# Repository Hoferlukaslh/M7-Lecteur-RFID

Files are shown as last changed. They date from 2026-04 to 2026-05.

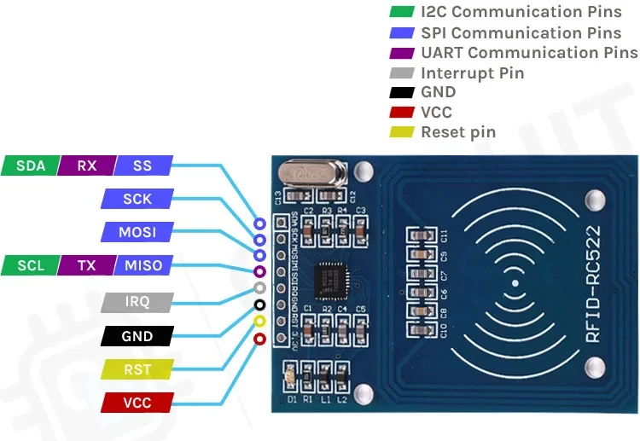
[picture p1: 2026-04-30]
Images/Hardware/RC522-RFID-Reader-Module-Pinout.webp

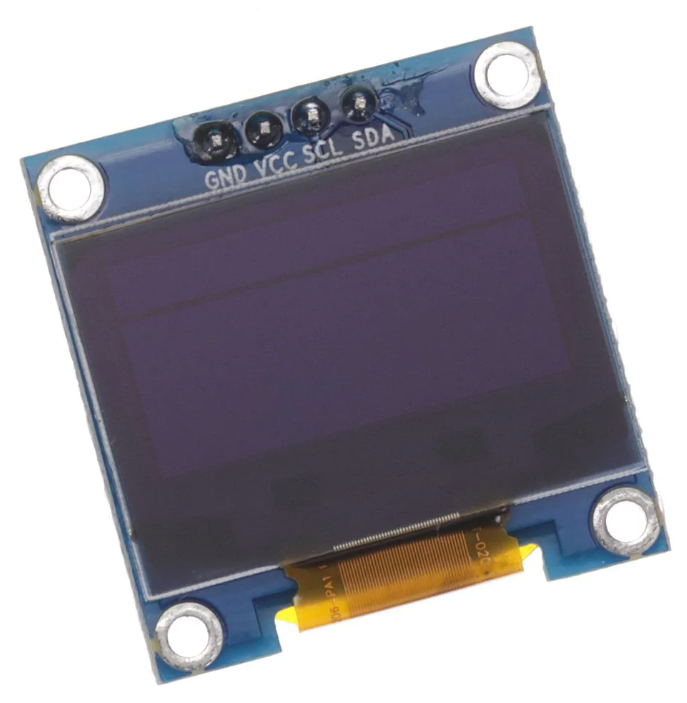
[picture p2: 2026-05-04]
Images/Hardware/OLED_SSD1305.png

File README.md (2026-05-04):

# M7-Lecteur-RFID
Ce dépôt contient l'ensemble des éléments du projet « Prototype de lecteur RFID » développé dans le cadre du module M7.    
L'objectif principal est de concevoir un système embarqué compact et bon marché, destiné à être dupliqué au sein des cellules de production des locaux de la NewTec.    
   
Ce système agit comme une interface physique et logique entre des tags RFID et un automate (PLC).   

[- Lien vers le dépot --](https://github.com/Hoferlukaslh/M7-Lecteur-RFID)

## Détails du projet 

### Architecture Globale et Communication
Le lecteur utilise une architecture de communication hybride pour s'adapter aux différents besoins de la ligne de production :

- Communication Automate (PLC) : Le système est universel et s'intègre avec tout type de contrôleur (Wago, Beckhoff, Raspberry Pi, etc.). Cette communication, servant à transmettre les ordres et les données lues, peut être activée ou désactivée selon les besoins de la cellule.

- Communication API (Wi-Fi) : De manière indépendante, le système interagit avec un serveur Node-RED via des requêtes API HTTP pour mettre à jour l'emplacement des palettes en temps réel dans une base de données. 

```mermaid
flowchart TD
    %% Définition des nœuds
    NR[Node-RED]
    DB[(BDD)]
    M7[Projet M7]
    PLC[Automate]

    %% Définition des liens et des étiquettes
    NR --> DB
    NR <-.->|"Requête API HTTP<br>(WiFi)<br>MàJ emplacement <br>palettes"| M7
    PLC -->|"Communication<br>pour ordres<br>(désactivable)"| M7
```

### Spécifications Matérielles
Le dispositif est conçu pour fonctionner de manière autonome dans un environnement industriel.

- Microcontrôleur : Choix libre.
- Module RFID : SBC-RFID-RC522.
- Connectivité : Wi-Fi avec antenne (choix libre).
- Alimentation : 24V DC (standard industriel).
- Cibles RFID : Petits disques de 15 mm x 3 mm disposant d'une capacité de stockage maximale de 106 octets.
- Intégration mécanique : Boîtier de protection imprimé en 3D. Il assure la sécurité du PCB et de l'antenne, tout en proposant un design universel pour une fixation rapide sur n'importe quelle structure machine sans gêner le flux des palettes.

### Spécifications Logicielles
Le firmware embarqué gère à la fois l'antenne RFID et la communication avec l'automate.  

#### Librairie RFID
Une bibliothèque logicielle est intégrée pour gérer la mémoire restreinte des tags avec les fonctions suivantes :

| Fonction | Description | 
| --- | --- |
| READ | Lecture des données présentes. |
| WRITE | Écriture avec écrasement du contenu existant. |
| APPEND | Ajout de nouvelles données à la suite (via gestion de pointeurs/marqueurs). |
| DELETE ALL | Effacement complet ou formatage du tag. |

#### Logique de Contrôle

| Fonction | Description | 
| --- | --- |
| Démarrage/Arrêt | Piloté sur commande du PLC. |
| Badge lu avec succès | Retour du contenu formaté au PLC et envoi de la mise à jour de position au serveur Node-RED. |
| Badge illisible/Erreur | Retour d'un code d'erreur spécifique au PLC. |
| Badge défectueux | Retour d'un code d'erreur critique (HS) au PLC. |
| Aucun badge | État d'attente, aucune action. |

### Ressources utilisées
#### Logiciels
| Logo | Application | Version | Utilité | Licence |
| :---: | :--- | :--- | :--- | --- |
|  | [**OnlyOffice**](https://www.onlyoffice.com) | 9.3.1 | Suite bureautique utilisée pour la rédaction et l’édition des documents du projet (DOCX, XLSX). | AGPL-3.0 |
|  | [**Draw.io**](https://github.com/jgraph/drawio) | 29.3.6 | Outil de conception de diagrammes. Utilisé pour la conception UML. | Apache 2.0 |
|  | [**VSCodium**](https://vscodium.com/) | v1.116.02821 | Editeur de texte avec extension (IDE) | MIT |
|  | [**Arduino IDE**](https://www.arduino.cc/en/software/) | 2.3.8 | IDE pour framework arduino (C++) | AGPL-3.0 |

### Modèle de Données et Optimisation
La contrainte matérielle majeure est la limite de 106 octets par tag. Une optimisation des données est indispensable.

#### Données des Palettes
- Identifiant de la palette.  
- Contenu de la palette : Jusqu'à 6 articles stockés sous le format `TTT-XXXXXX-VV-R` (Type de l'article, Code unique, Version, Révision).

#### Données des Badges Client :
- Identifiant de la palette.  
- Pseudonyme du client (10 caractères).  
- Données de production pour 4 cellules : Date, heure, et identifiant de la cellule ayant effectué l'opération.

## Livrables Attendus
L'arborescence de ce projet est divisée selon les livrables suivants :  

| Livrables | Description | 
| --- | --- |
| [Hardware](./Hardware/) | Dossier électronique contenant les schémas de principe, le routage PCB (fichiers Gerber) et la nomenclature (BOM). |
| [Mechanical](./Firmware/) | Fichiers 3D (STL/STEP) pour l'impression du boîtier de protection. |
| [Firmware](./Firmware/) | Code source documenté du microcontrôleur, incluant la pile de communication et la librairie RFID. |
| [Documents](./Documents/) | CdC et Journal, Documentation technique du projet (Table de communication décrivant le protocole PLC, les endpoints de l'API HTTP, et la cartographie d'optimisation mémoire) |
| [Images](./Images/) | Dossier contenant des images utilisés dans le projet. |

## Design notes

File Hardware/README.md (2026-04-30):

Dossier électronique contenant les schémas de principe, le routage PCB (fichiers Gerber) et la nomenclature (BOM).

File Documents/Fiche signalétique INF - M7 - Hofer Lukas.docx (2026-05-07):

2026 | AUTEUR : Prénom Nom EXPERTS : Prénom Nom, Ecole Supérieure Technique Prénom Nom, Nom de l’entreprise | « LOGO DE L’ENTREPRISE » Ou vide
Lecteur RFID

Objectifs

Développer un système embarqué compact et universel de lecture et d'écriture de tags RFID pour équiper les cellules de production de la NewTec.

Résultats

Conception et réalisation d'un circuit imprimé sur mesure intégrant un microcontrôleur ESP32-C6/S3, un module RFID RC522, et un étage d'alimentation abaisseur 24V vers 3.3V.

Développement d'un firmware sur FreeRTOS capable de gérer simultanément les bus de communication SPI (RFID), I2C (écran) et RS485 (automate).

Applications

Identification et traçabilité en temps réel des palettes circulant sur les différentes lignes de production automatisées.

Suivi décentralisé des étapes de production par horodatage et enregistrement des cellules traversées directement sur le tag physique.

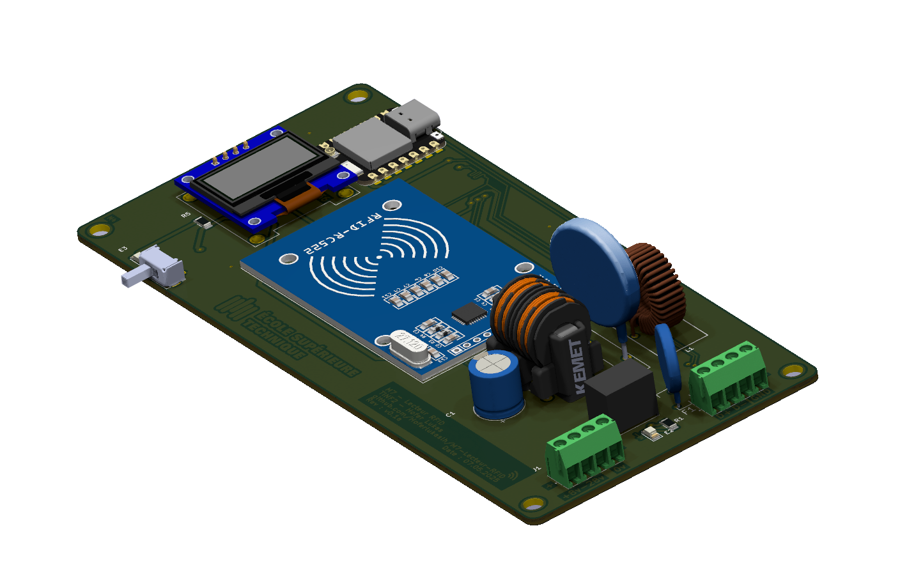
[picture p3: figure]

EST - Ecole Supérieure Technique Porrentruy

Informaticien·ne diplômé·e ES – Travail de module : M7-Internet des objets

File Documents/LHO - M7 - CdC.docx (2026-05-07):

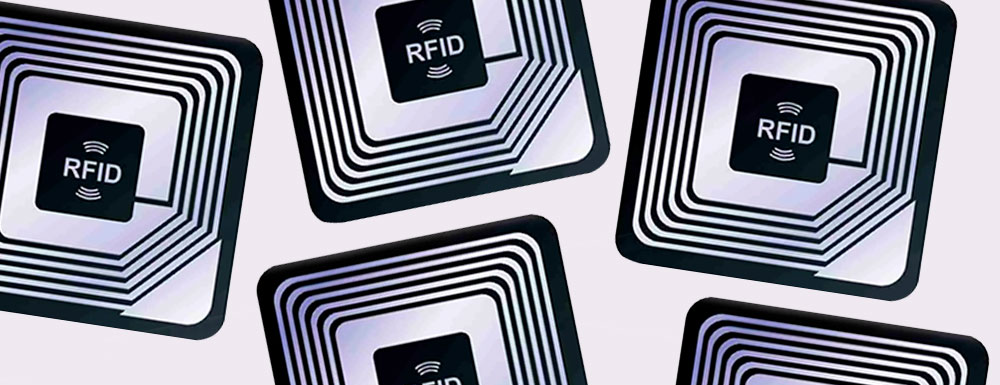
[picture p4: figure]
17 indicateurs de production à suivre - SupplyChainInfo

Lecteur RFID

M7 - Cahier des charges

Auteur :

Hofer Lukas
Technicien ES en informatique 2e année

Enseignants :

Claude Fahrni
Montfermé Arnaud
Montavon Dominique

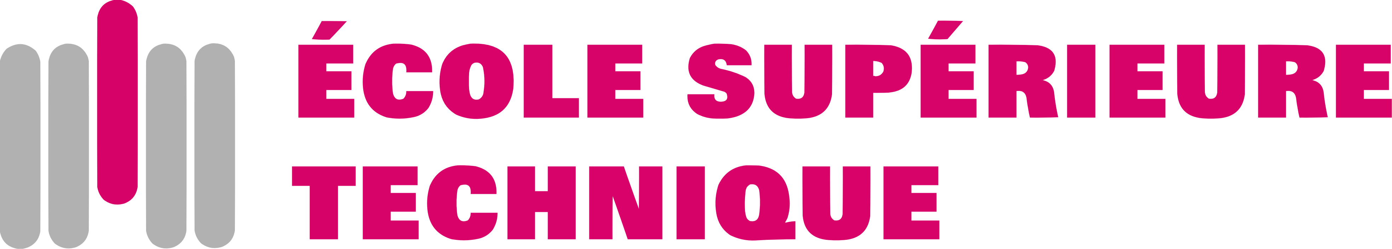
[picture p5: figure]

Avril 2026

École supérieure technique

# Introduction

Ce document définit les spécifications techniques et fonctionnelles pour le développement d'un système embarqué de lecture et d'écriture de tags RFID. Il s'inscrit dans le cadre global du projet « Prototype de lecteur RFID ».

Ce projet consiste à mettre au point un système embarqué compact et bon marché qui sera dupliqué et installé dans diverses cellules au sein des locaux de la NewTec. Le système servira d'interface physique et logique entre les tags RFID (en forme de petits disques) et le PLC.

## Architecture Globale et Communication

Le système possède désormais une architecture de communication hybride permettant de s'adapter aux différents besoins de la ligne de production.

- Communication Automate (PLC) : Le système doit être universel pour s'intégrer facilement à tout type de contrôleur (Wago, Beckhoff, etc.) ou Raspberry Pi. Cette communication PLC doit pouvoir être activable ou désactivable selon les besoins de la cellule (via un interrupteur par exemple).
- Protocole Automate : Le choix du protocole est à définir, avec une structure de trame stricte pour l'envoi des données lues et la réception des demandes d'écriture.
- Communication API (Suivi BDD) : Indépendamment de l'automate, le système M7 doit interagir avec un serveur Node-RED via des requêtes API HTTP. L’objectif est de Mettre à jour l'emplacement des palettes en temps réel dans une base de données (BDD) à chaque lecture d'un tag.

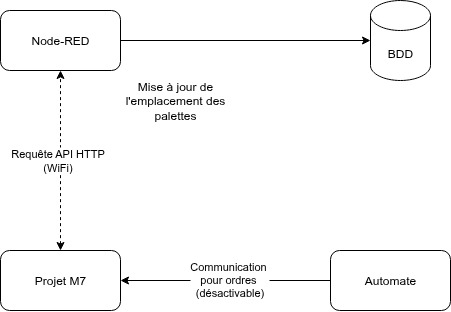
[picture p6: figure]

# Spécification matériel

Le système doit être conçu pour un environnement industriel et autonome dans son traitement local.

- Microcontrôleur : Choix libre.
- Communication API : Wi-Fi (antenne : choix libre)
- RFID : Module SBC-RFID-RC522
- Alimentation : Le système sera alimenté en 24V DC (standard industriel).
- Tags RFID cibles :
  - Dimensions physiques : 15 mm x 3 mm.
  - Capacité de stockage mémoire : 106 octets (bytes) maximum.
- Conception Électronique (PCB) :
  - Création du schéma de principe.
  - Routage de la carte électronique (PCB).
  - Fabrication et assemblage.
- Intégration Mécanique :
  - Conception et modélisation 3D d'un boîtier de protection.
  - Fabrication par impression 3D.

## Conception du boîtier et intégration

Le système embarqué devra être intégré dans un boîtier de protection réalisé par impression 3D.

La conception mécanique de ce boîtier devra répondre à deux exigences principales :

- Protection : Assurer la sécurité de la carte électronique et de l'antenne RFID dans un environnement industriel standard.
- Installation universelle : Prévoir un design et des points de fixation simples permettant de monter le boîtier facilement et rapidement sur n'importe quelle structure de machine ou au sein d'une zone automate.

L'encombrement global devra être pensé pour ne pas gêner le flux des palettes ni l'accès aux autres équipements.

# Spécifications Logicielles

Le microcontrôleur devra embarquer un programme gérant à la fois l'antenne RFID et le dialogue avec l'automate.

## Librairie RFID

Développement ou intégration d'une bibliothèque logicielle permettant la gestion de la mémoire restreinte des tags avec les fonctions suivantes :

- READ : Lecture des données présentes sur le tag.
- WRITE : Écriture de données en écrasant le contenu existant.
- APPEND : Ajout de nouvelles données à la suite des données existantes (nécessite une gestion des pointeurs ou marqueurs de fin de fichier).
- DELETE ALL : Effacement complet ou formatage de la mémoire du tag.

## Logique de Contrôle

Le programme principal doit réagir aux requêtes selon la logique suivante :

- Démarrage/Arrêt Gérer le lancement et l'arrêt de la procédure de lecture sur commande du PLC.
- Badge lu avec succès Retourner l'intégralité du contenu formaté au PLC et envoyer la mise à jour de position au serveur HTTP Node-RED.
- Badge illisible ou Erreur Retourner un code d'erreur spécifique au PLC.
- Badge défectueux Retourner un code d'erreur critique (HS) au PLC.
- Aucun badge Ne déclencher aucune action (état d'attente).

# Modèle de Données

La contrainte majeure du projet est la limite physique de 106 octets par tag RFID.

## Données des palette

- Identifiant de la palette
- Contenu de la palette : Jusqu'à 6 articles au format TTT-XXXXXX-VV-R

T | T | T | - | X | X | X | X | X | X | - | V | V | - | R
Type de l’article | | | | Code unique de l’article | | | | | | | Version | | | Révision

Exemple :

Paramètre | Contenu
Identifiant de la palette | P2
Emplacement 1 | 001 - 000000 - 00 - 0
Emplacement 2 | 010 - 000000 - 00 - 1
Emplacement 3 | 100 - 000000 - 00 - 1
Emplacement 4 | 900 - 000000 - 00 - 2
Emplacement 5 | 999 - 000000 - 00 - 8
Emplacement 6 | 888 - 000000 - 00 - 9

Une optimisation est nécessaire afin de réduire l’espace mémoire utilisé.

## Données des badges client

- Identifiant de la palette
- Pseudonyme du client : 10 caractères.
- Données de production
  - Date et heure
  - Identifiant des cellules ayant effectuée les opérations (fixé à 4 actuellement)
  - Identifiant de la palette utilisé pour la prodution

Exemple :

Paramètre | Contenu
Identifiant de la palette | P2
Pseudonyme | HoferLukas
Identifiant cellule 1 | C1
Date et heure cellule 1 | 12:05:02 - 22/04/26
Identifiant cellule 2 | C2
Date et heure cellule 2 | 12:06:08 - 22/04/26
Identifiant cellule 3 | C3
Date et heure cellule 3 | 12:08:55 - 22/04/26
Identifiant cellule 4 | C4
Date et heure cellule 4 | 12:10:32 - 22/04/26

Une optimisation est nécessaire afin de réduire l’espace mémoire utilisé.

# Livrables Attendus

- Dossier électronique Fichiers schématiques, fichiers Gerber pour la fabrication du PCB, et BOM (Nomenclature).
- Dossier mécanique Fichiers STL/STEP pour l'impression 3D du boîtier.
- Code source Firmware du microcontrôleur documenté, incluant la librairie RFID et la pile de communication.
- Table de communication Document décrivant le protocole choisi, la structure des trames d'échange PLC, les endpoints de l'API HTTP, et la cartographie d'optimisation mémoire des 106 octets.
- Prototype fonctionnel Carte électronique assemblée dans son boîtier avec firmware opérationnel.

LHO - M7 - CdC - v2.docx Page 2 sur 6 LHO/30.04.2026

Cahier des charges M7 TINF2

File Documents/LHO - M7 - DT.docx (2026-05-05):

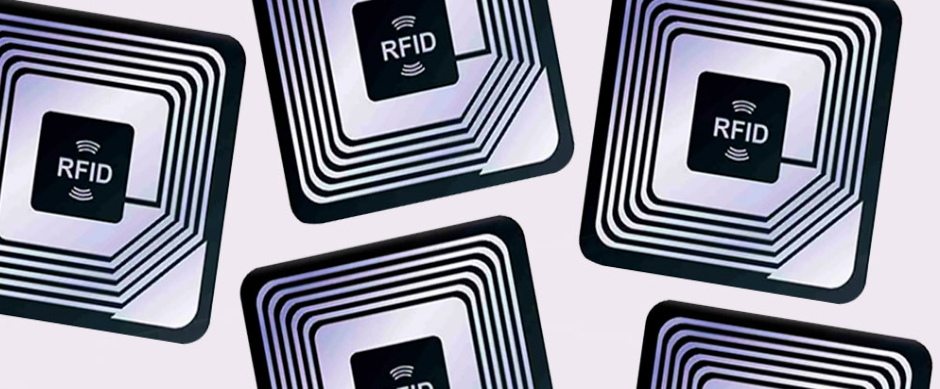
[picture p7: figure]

Lecteur RFID

M7 - Documentation technique

Auteur :

Hofer Lukas
Technicien ES en informatique 2e année

Enseignants :

Claude Fahrni
Arnaud Montfermé
Montavon Dominique


Avril - Juin 2026

École supérieure technique

# 1. Introduction

Ce module d’apprentissage a pour objectif de couvrir l’ensemble du cycle de développement d'un système embarqué de lecture et d'écriture de tags RFID , depuis l’analyse des besoins jusqu’aux phases de fabrication, de test et de validation du prototype.

Il met l’accent sur les bonnes pratiques de conception matérielle et logicielle, l'intégration dans un environnement industriel, et l’utilisation d’outils de développement professionnels.

Les compétences visées sont les suivantes :

- Conception électronique : Création de schémas de principe, routage de la carte électronique (PCB) et assemblage des composants.
- Conception mécanique : Modélisation 3D et impression d'un boîtier de protection adapté à une installation universelle sur ligne de production.
- Développement logiciel embarqué : Programmation d'un microcontrôleur et intégration d'une librairie RFID pour la lecture, l'écriture et la gestion d'une mémoire restreinte.
- Architecture de communication : Mise en œuvre d'une communication hybride comprenant un protocole strict avec un automate (PLC) et des requêtes API HTTP vers Node-RED.

## 1.1 Personnes impliquées

Élève impliqué :

- Hofer Lukas : technicien ES en informatique 2e année

Enseignants impliqués :

- Claude Fahrni : responsable du module et suivit technique du projet
- Montfermé Arnaud : suivi technique du projet
- Montavon Dominique : suivi technique du projet

## 1.2 Directives générales

### 1.2.1 Délais

Réedition des documents | 12 Juin 2026
Présentation | 17 Juin 2026
Remise du travail complet | 18 Juin 2026

### 1.2.2 Livrables

- Cahier des charges
- Documentation technique (ce présent document)
- Présentation
- Planification (avec suivit)
- Journal de travail
- Prototype fonctionnel (PCB)

# 2. Spécifications du système

Le projet consiste à développer un appareil embarqué permettant à l’installation de :

Assurer l'interface physique et logique entre des tags RFID et un automate industriel (PLC).

Identifier et tracer les palettes circulant sur la ligne de production en temps réel.Gérer le stockage de données de production et d'articles dans une mémoire restreinte de 106 octets.

Communiquer de manière hybride avec un automate (commandes locales) et un serveur Node-RED (mise à jour de base de données via API).

## 2.1 Cible

Ce projet part de trois constats principaux :

- Besoin de modularité : Nécessité d'un système compact et bon marché pouvant être dupliqué et installé facilement sur n'importe quelle structure.
- Interopérabilité : Besoin d'un lecteur universel capable de communiquer avec différents types de contrôleurs (Wago, Beckhoff, Raspberry Pi).
- Digitalisation : Volonté d'automatiser la mise à jour des emplacements de palettes dans une base de données centrale indépendamment de l'automate.

## 2.2 Exigences fonctionnelles

Les fonctionnalités suivantes devront être implémentées

ID | Catégorie | Description de l'exigence | Priorité
REQ-F-001 | RFID | Le système doit permettre la lecture (READ), l'écriture (WRITE) et l'ajout (APPEND) de données sur les tags. | Haute
REQ-F-002 | Comm. PLC | Le système doit échanger des trames de données strictes avec l'automate pour l'envoi des lectures et la réception d'ordres. | Haute
REQ-F-003 | Sync. API | Le système doit envoyer une requête HTTP à un serveur Node-RED à chaque lecture réussie pour mettre à jour la BDD. | Haute
REQ-F-004 | Gestion Mémoire | Le système doit optimiser l'encodage des données pour respecter la limite physique de 106 octets par tag. | Haute
REQ-F-005 | Diagnostic | Le système doit retourner des codes d'erreurs spécifiques au PLC en cas de tag illisible, défectueux ou absent. | Moyenne
REQ-F-006 | Contrôle Local | La communication avec l'automate doit pouvoir être activée ou désactivée manuellement via un interrupteur. | Basse
REQ-F-007 | Intégration | Implémentation sur PCB et intégration dans un boitier pouvant facilement être integré dans un environnement industriel. | Basse

# 3. Conception Matérielle

La conception matérielle fait partie du premier sprint. Elle sert à concevoir un prototype le plus rapidement possible.

## 3.1 Vue d'ensemble de l'architecture

L'architecture matérielle proposée a été pensée pour répondre aux contraintes de compacité, de coût et de double communication (Automate et Base de données).

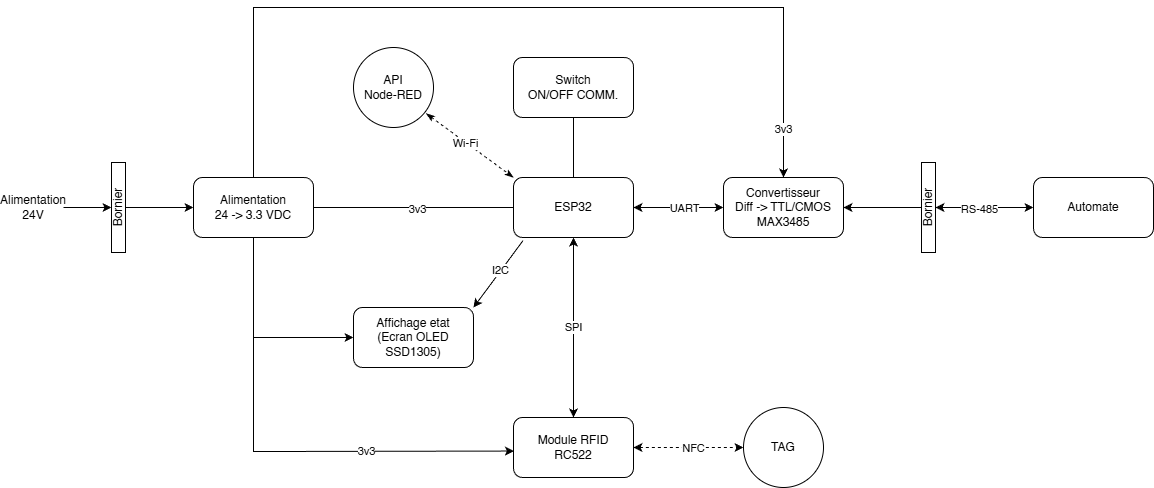
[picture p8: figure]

Le système s'articule autour d'un microcontrôleur central faisant le pont entre le monde industriel (borniers 24V et RS-485) et les périphériques de lecture matérielle et de communication sans fil (RFID et Wi-Fi).

## 3.1 Choix des composants

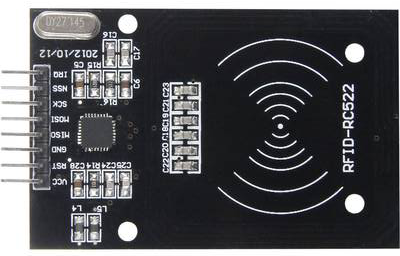
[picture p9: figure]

### 3.1.1 Module de lecture RFID : RC522

Le choix de ce module n'a pas été libre, il a été imposé par le cahier des charges. Il s'agit d'un lecteur RFID fonctionnant avec une tension logique de 3.3V et qui communique avec le microcontrôleur via le bus SPI.

### 3.1.2 Interface Automate (PLC) : RS-485 et MAX3485

Pour garantir la compatibilité universelle du prototype avec différents contrôleurs industriels (Wago, Beckhoff, etc.), l'interface de communication physique devait être robuste.

- Bus de terrain RS-485 : Le standard industriel RS-485 a été choisi pour le câblage vers l'automate. Ses signaux différentiels offrent une forte résistance aux interférences électromagnétiques fréquentes dans les milieux de production.
- Convertisseur : L'ESP32 utilisant des signaux TTL/CMOS sur son port UART, une puce de conversion MAX3485 est intégrée. Elle sert de pont pour traduire les signaux logiques de l'ESP32 en signaux différentiels exploitables par l'automate via le bornier de raccordement. L'avantage du MAX3485 est qu'il est alimenté directement en 3.3V, simplifiant ainsi le circuit.

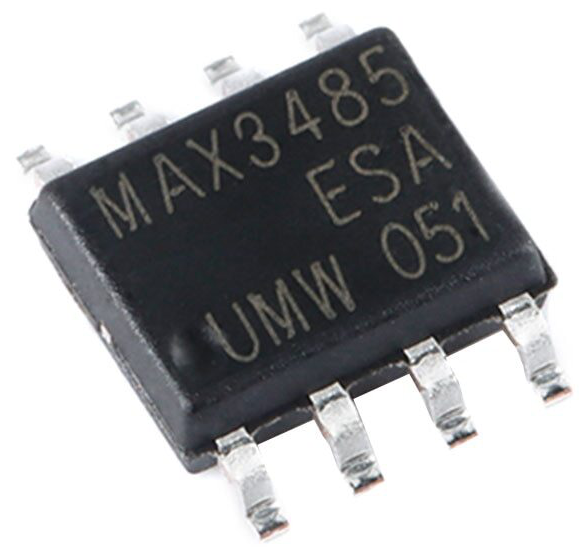
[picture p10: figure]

### 3.1.3 Affichage / Autodiagnostique : Ecran OLED


Cet affichage permet de remonter le diagnostic local (état d'attente, badge lu avec succès, badge illisible, ou badge défectueux). Le choix s'est porté sur l’afficheur OLED basé sur le contrôleur SSD1305, car il est déjà à disposition. (exigences REQ-F-005)

### 3.1.4 Interfaces de contrôle local et de diagnostic

Afin de répondre aux exigences d'intégration logicielle et matérielle du cahier des charges (exigences REQ-F-006), des interfaces physiques dédiées aux opérateurs ont été ajoutées :

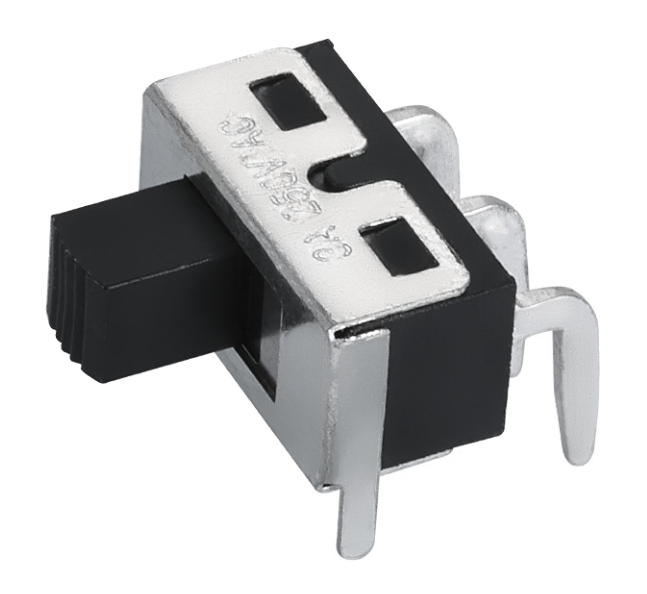
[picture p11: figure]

- Switch ON/OFF COMM : Un interrupteur matériel relié à une broche d'entrée de l'ESP32. Il permet à l'opérateur d'activer ou de désactiver la communication série avec l'automate. J’ai choisi de prendre un switch latéral pour l’accessibilité à l’éxtérieur du boitier.

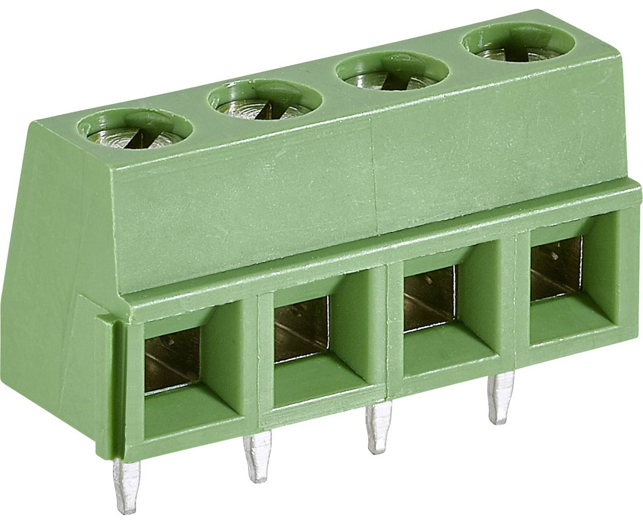
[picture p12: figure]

### 3.1.5 Branchement / Liaison

Afin de garantir une intégration rapide et une utilisation aisée sur les lignes de production, les liaisons physiques entre la carte électronique et l'extérieur du boîtier sont réalisées au moyen de borniers (terminal blocks).

Ce choix de conception est particulièrement adapté aux contraintes du milieu industriel pour les raisons suivantes :

- Facilité et rapidité d'installation : Le raccordement de l'appareil s'effectue à l'aide d'un simple tournevis, sans nécessiter de fiches spécifiques, d'outils de sertissage complexes ou de soudures sur site.
- Maintenance simplifiée (Plug & Play) : En cas de défaillance matérielle, l'opérateur peut dévisser ou débrocher les borniers pour retirer le lecteur défectueux et brancher un nouveau prototype en quelques secondes.

### 3.1.6 Microcontroleur : ESP32-S3/C6

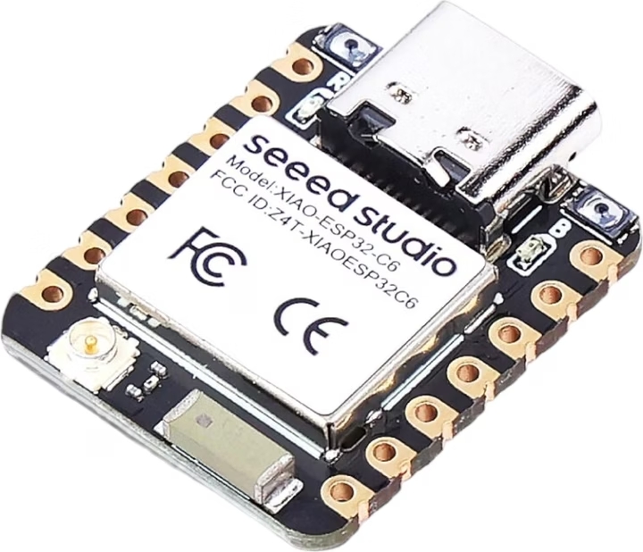
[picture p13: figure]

Pour le rôle de traitement central, le choix s'est porté sur le microcontrôleur Seeed Studio XIAO ESP32S3/C6. Ce composant a été sélectionné pour plusieurs raisons stratégiques permettant de répondre aux contraintes d'encombrement et de communication du cahier des charges :

- Connecteur pour antenne externe (U.FL / IPEX) : Le XIAO ESP32S3/C6 est équipé d'un connecteur physique permettant de déporter l'antenne Wi-Fi à l'extérieur du boîtier ou de la machine. C'est un avantage décisif pour contourner les interférences des structures métalliques industrielles et garantir des requêtes API HTTP stables vers le serveur Node-RED.
- Intégration optimisée sur PCB : Grâce à ses pastilles crénelées (castellated holes), ce module peut être soudé directement à plat en tant que composant monté en surface (CMS) sur la carte électronique mère, garantissant une forte résistance mécanique aux vibrations de la ligne de production.
- Tension logique (3.3V) : Le microcontrôleur fonctionne avec une tension de 3.3V, ce qui lui permet de communiquer directement avec le module RC522 et la puce MAX3485 sans nécessiter de convertisseurs de niveaux logiques (Level Shifters) supplémentaires, simplifiant ainsi le routage global.
- Maturité : ESP32 est une plateforme extrêmement mature et standardisée. Elle dispose d'une vaste communauté, d'une excellente documentation et de nombreuses bibliothèques éprouvées. Cela permet de réduire les risques lors du développement logiciel et d'accélérer la réalisation du prototype.
- Gestion multi-bus (Optimisation des I/O) : Bien que le format compact du XIAO n'offre que 11 broches GPIO latérales, l'architecture matérielle a été rigoureusement calculée pour les exploiter à 100 %. Grâce à la matrice GPIO programmable de l'ESP32 (qui permet de réassigner librement les bus de communication pour faciliter le routage du PCB), ces 11 broches suffisent exactement à couvrir l'intégralité des périphériques :
  - 5 broches pour le module RFID-RC522
  - 3 broches pour l'interface automate via le MAX3485
  - 2 broches dédiées au diagnostic visuel via l’écran (I2C)
  - 1 broche pour l'interrupteur matériel de la communication locale
- Disponibilité et expérience : Ayant auparavant travaillé avec ce même modèle, cela élimine les temps d'apprentissage (pas de surprises techniques) et sécurise la phase de développement logiciel. De plus, la disponibilité immédiate d'un modèle d'évaluation permet de démarrer la phase de prototypage et les premiers tests sans subir de délais d'approvisionnement (ESP32-C6).

### 3.1.7 Gestion de l'alimentation : (24v ->3v3)

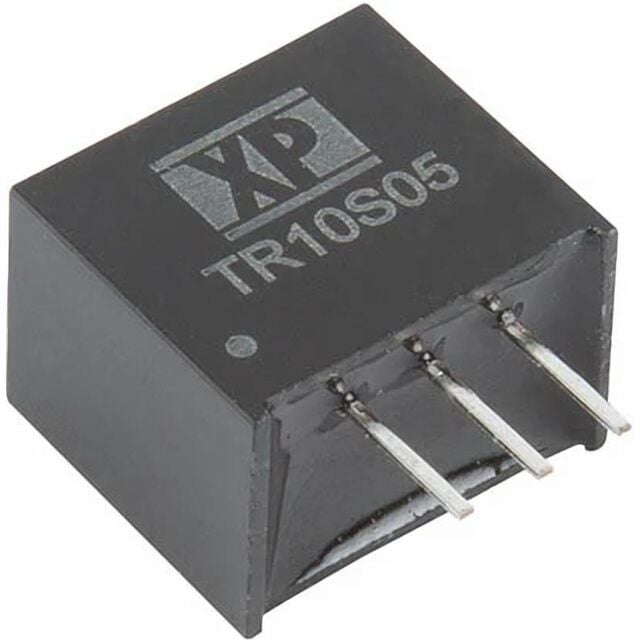
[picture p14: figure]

Le système devant s'intégrer directement dans les cellules industrielles, l'alimentation primaire fournie en entrée est le standard 24V DC. Pour abaisser et réguler cette tension, le choix s'est porté sur le convertisseur DC-DC TSR 1-2433E.

Il s'agit d'un régulateur à découpage, capable d'accepter une large plage de tension en entrée (de 6V à 36V) pour fournir une tension de sortie stable de 3.3V.

Il peut délivrer un courant allant jusqu'à 1A (1000 mA), avec une excellente efficacité énergétique pouvant atteindre 88%.

Cette haute efficacité minimise considérablement la dissipation thermique, ce qui est idéal pour un boîtier fermé imprimé en 3D, tout en garantissant un encombrement minimal sur le PCB.

### 3.1.8 Bilan de puissance (Calculs)

Afin de valider le choix du régulateur TSR 1-2433E, un bilan de puissance a été réalisé en prenant en compte la consommation maximale théorique de chaque composant actif sur la ligne 3.3V :

- Microcontrôleur ESP32 (S3 ou C6) : Lors d'un pic d'émission Wi-Fi (transmission 802.11b à pleine puissance), la consommation maximale est d'environ 354 mA.
- Module de lecture RFID (RC522) : En phase de fonctionnement et de lecture active (émission du champ à 13.56 MHz), la consommation maximale est de 26 mA.
- Transceiver RS-485 (MAX3485) : Le courant d'alimentation de la puce est d'environ 2.2 mA au maximum. En ajoutant le courant de pilotage sur le bus avec une charge standard, on peut estimer un maximum d'environ 60 mA.
- Afficheur OLED et signalisation : L'écran OLED tous pixels allumés et les deux LEDs de statut consomment ensemble un maximum estimé à 50 mA.

Calcul de la charge totale maximale :

354 mA+26 mA+60 mA+50 mA=490 mA

Le courant maximal appelé par le circuit en pic d'activité est d'environ 490 mA. Le régulateur TSR 1-2433E pouvant fournir jusqu'à 1000 mA, le système fonctionnera à moins de 50 % de la capacité maximale du convertisseur.

Cette large marge de sécurité garantit que l'alimentation ne subira aucune surchauffe ni chute de tension, assurant ainsi la stabilité de l'ensemble du système.

## 3.2 Schéma de principe et implémentation électrique

Cette section détaille la traduction des choix matériels en un schéma électronique concret. Le circuit a été divisé en plusieurs blocs fonctionnels pour faciliter le routage et la compréhension du système.

### 3.2.1 Bloc Alimentation (Protections, Filtrage et Régulation)

Le circuit d'alimentation est le bloc le plus critique, chargé de sécuriser et d'abaisser la tension industrielle de 24V vers le 3.3V logique. Il est divisé en trois étages successifs :

- Étage de protection (Entrée +8V à 28V) : L'alimentation arrive par le bornier J1. Elle traverse immédiatement une diode Schottky D1 (BX36_R1) pour bloquer toute inversion de polarité, suivie d'un fusible réarmable F1 (PTC 1A) contre les surintensités. Une diode TVS D2 (SMAJ28A, Vz = 28V) écrête les surtensions transitoires.
- Étage de filtrage CEM (EN 55032 Classe B) : Pour respecter les normes d'émissions, la tension (désormais entre +7V et 27.6V) passe par un filtre rigoureux. Une varistance RV1 (20D470K) protège l'entrée du filtre. Le lissage basse fréquence est assuré par l'inductance L1 (300 µH) et les condensateurs C1 (470 µF) et C2 (4.7 µF). Le filtrage haute fréquence et asymétrique est géré par l'inductance de mode commun L2 (5 mH) et le condensateur C3 (10 µF).
- Étage de régulation : Le convertisseur DC-DC PS1 (TSR 1-2433E) abaisse la tension à +3V3. La sortie est stabilisée par un condensateur C4 (22 µF) et alimente une LED de fonctionnement E2 via une résistance R1 (68 R)

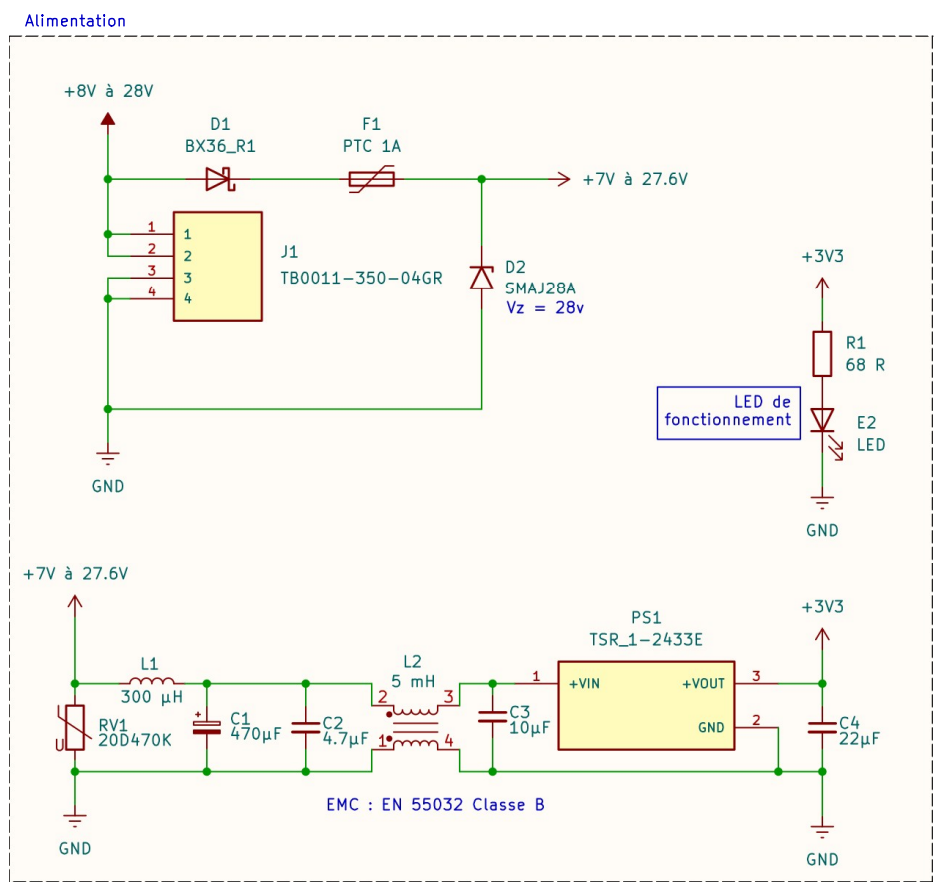
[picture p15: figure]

### 3.2.2 Microcontrôleur

Le composant U1 (XIAO-ESP32-C6, compatible S3) centralise toutes les liaisons.

Alimenté en +3V3, il orchestre les différents bus de communication (SPI pour le RFID, I2C pour l'écran, UART pour le RS-485) ainsi que les entrées/sorties numériques directes (comme le switch de commande).

### 3.2.3 Communication Automate (Interface RS-485)

L'interface de communication vers le PLC est gérée par le transceiver U3 (MAX3485CSA+T), alimenté en +3V3.

- Logique de contrôle : Les broches DI (Data In) et RO (Receiver Out) sont reliées au port UART de l'ESP32 (broches TX et RX). Les broches d'activation DE (Driver Enable) et RE (Receiver Enable) sont court-circuitées et pilotées par une seule broche GPIO de l'ESP32 : un état HAUT (HIGH) active l'envoi de données, tandis qu'un état BAS (LOW) place la puce en mode écoute.
- Liaison physique : Les signaux différentiels de sortie D+ et D- sont dirigés vers le bornier J2. Une résistance de terminaison R2 (120 R) est placée en parallèle entre ces deux lignes pour empêcher la réflexion des signaux en bout de ligne.

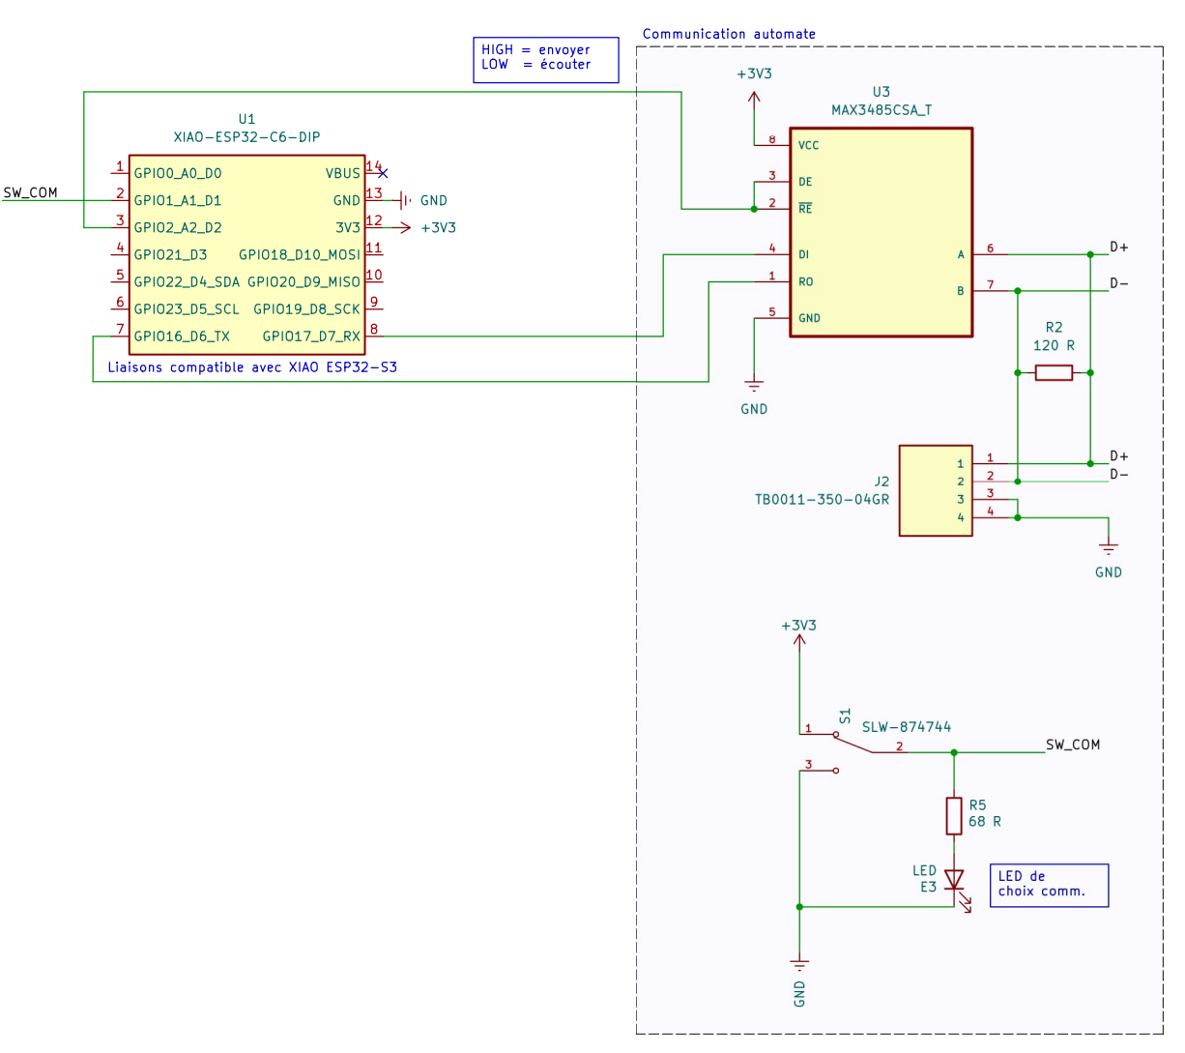
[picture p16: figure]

### 3.2.4 Lecteur RFID

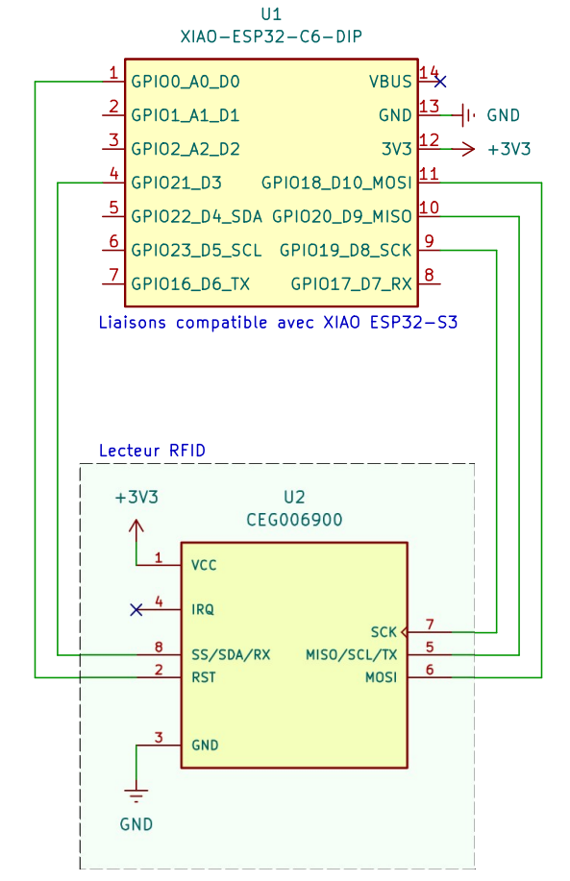
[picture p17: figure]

Le module U2 (RC522) est raccordé de manière classique pour une communication SPI. Il reçoit son alimentation (+3V3 et GND) et échange les données via les lignes MOSI, MISO et SCK.

La sélection du composant se fait par la broche SDA/SS, et la réinitialisation matérielle via la broche RST.

### 3.2.5 Affichage de diagnostic et Contrôle local

Ces éléments permettent l'interaction directe avec l'opérateur :

- Écran OLED (E1) : Connecté sur le bus I2C (SCL et SDA), il fonctionne en 3.3V. Des résistances de tirage (pull-up) R3 et R4 de 4k7 ont été prévues sur le schéma de manière optionnelle, selon que le module OLED utilisé les intègre déjà ou non en interne.
- Switch de communication : Un interrupteur matériel (SLW-874744) est relié à la broche SW_COM de l'ESP32 et à la masse (GND), permettant de basculer l'état de la communication PLC. Une LED de statut E3, protégée par une résistance R5 (68 R), est associée à ce circuit pour indiquer visuellement le choix de la communication.

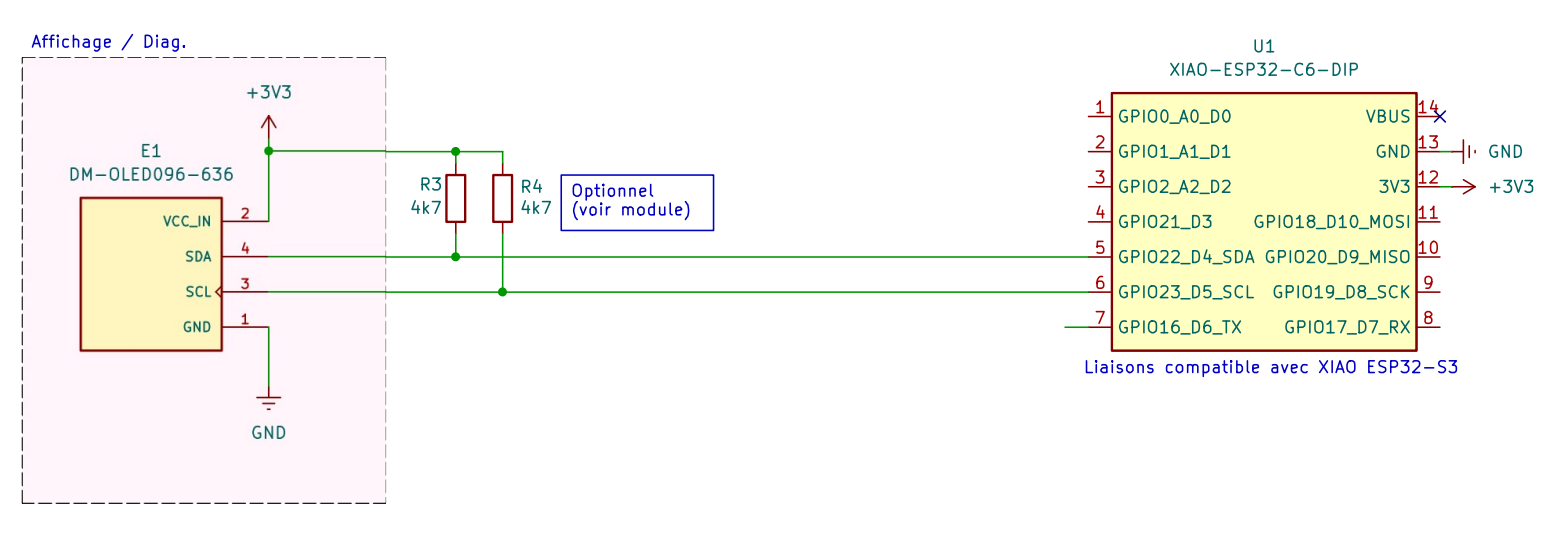
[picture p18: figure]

A FAIRE : SIMPLE AFFICHAGE DIAG. (LED + R)

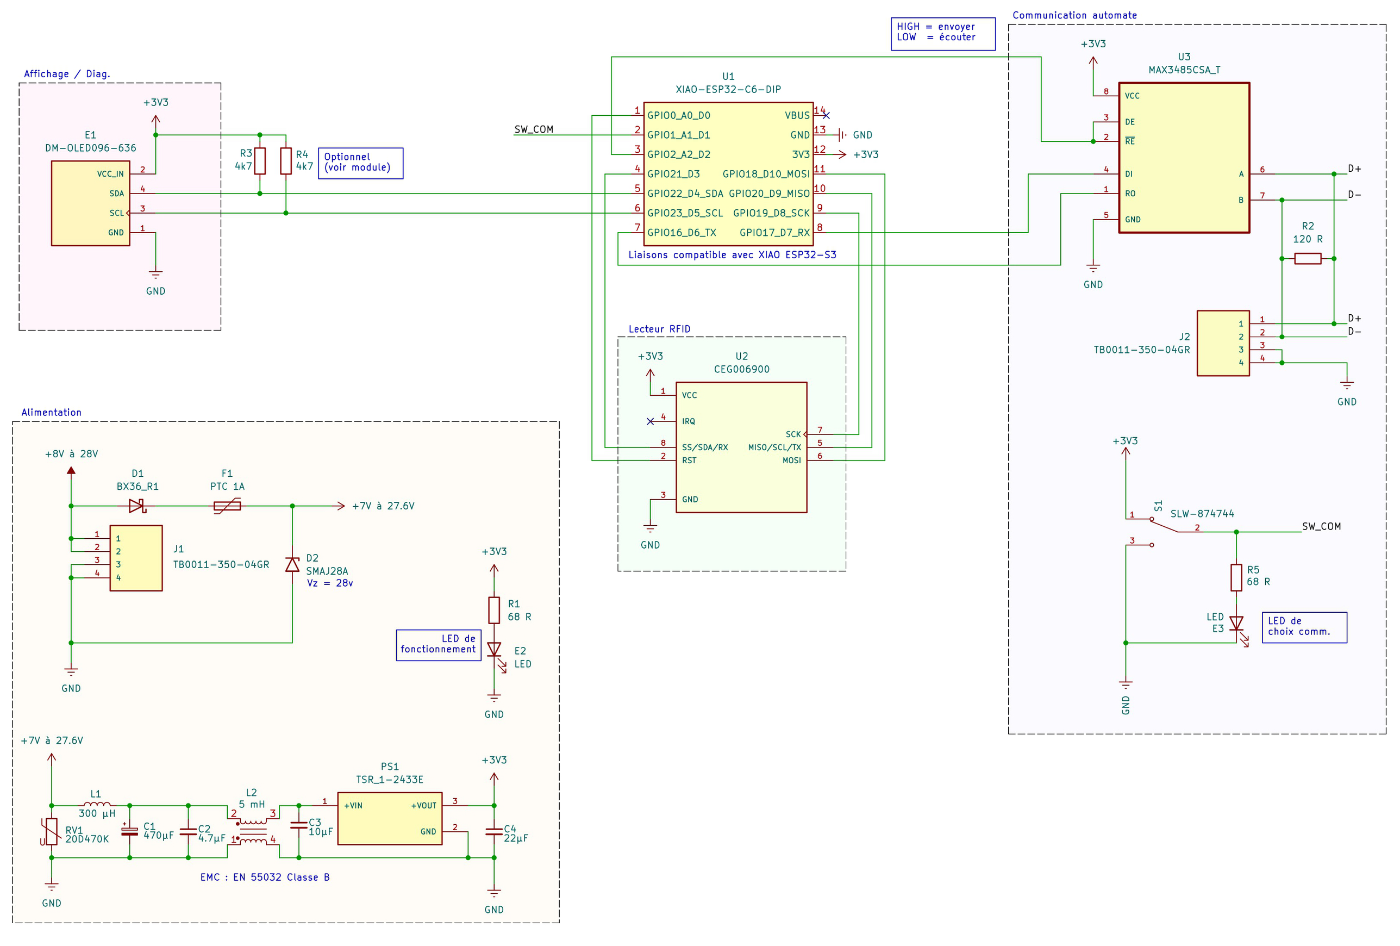
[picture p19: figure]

LHO - M7 - DT.docx Page 2 sur 1 LHO/06.05.26

Documentation technique M5 TINF2

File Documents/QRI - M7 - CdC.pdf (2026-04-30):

## Cahier des charges Système embarqué lecture/écriture Tags RFID

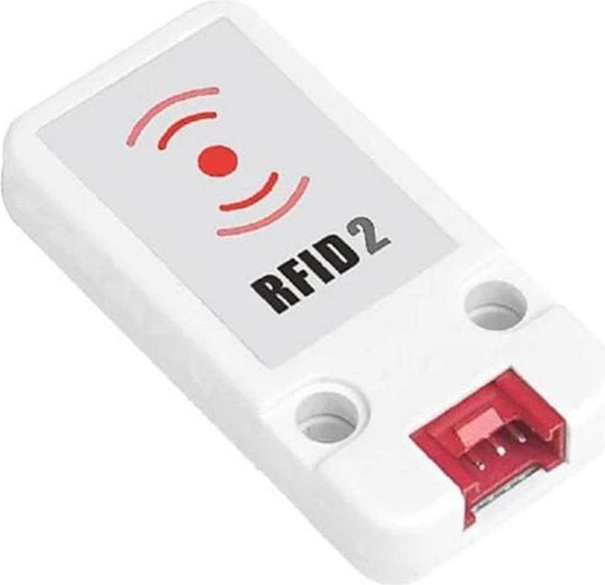
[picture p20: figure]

Figure 1 - Lecteur RFID WS1850S - Digitec

NewTec

mardi, 4 novembre 2025

CDC – Lecteur Tag RFID | 04.11.2025
Newtec | i

## Table des matières

Figures | i
Tableaux | i
1 | Introduction | 2
2 | Concept | 2
3 | Fonctionnent d’un tag RFID | 2
4 | Tags RFID de l’espace Newtec | 2
5 | Contraintes | 3
5.1 | Structure des données stockées dans les tags RFID | 3
5.2 | Communication et décodage des données au niveau PLC | 4
5.3 | Système embarqué | 4
5.4 | Microcontrôleur | 5
6 | Travaux | 5
6.1 | Système embarqué | 5
6.2 | Programmation | 6
6.2.1 | Librairie | 6
6.2.2 | Programme | 6
6.3 | Circuit imprimé (optionnel) | 7
7 | Adaptation du CDC | 8

## Figures

Figure 1 - Lecteur RFID WS1850S - Digitec | 1
Figure 2 - Tag RFID de l'espace Newtec | 2
Figure 3 - Schéma de codification des articles | 3
Figure 4 - Empreinte palette | 5
Figure 5 - Convoyeur tags RFID de la cellule d'assemblage | 5

## Tableaux

Tableau 1 - Taille mémoire pour stockage des informations liées aux palettes | 3
Tableau 2 - Taille mémoire pour stockage des informations liées aux badges | 4

Newtec | 2

## 1 Introduction

Ce cahier des charges se base sur le cahier des charges principal « Prototype de lecteur RFID ». Il contient toutes informations et contrainte liées au développement du système embarqué qui servira à la lecture et l’écriture de tags RFID.

## 2 Concept

Ce projet consiste à mettre au point un système embarqué compact et bon marché permettant la lecture et l’écriture de tags RFID.
Ce système sera dupliqué et installé dans diverses cellules se trouvant dans les locaux de la NewTec.
Il se doit d’être universel afin de garantir d’être facilement intégré à tout type de PLC (Wago, Beckhoff, ...) voir même RaspBerry.

## 3 Fonctionnent d’un tag RFID

Un tag RFID fonctionne grâce à un système de communication sans fil entre une puce électronique intégrée dans le tag et un lecteur RFID. Le lecteur émet un champ électromagnétique qui alimente le tag passif (qui n'a pas de batterie) pour qu'il puisse réveiller sa puce et lui transmettre les données stockées.

## 4 Tags RFID de l’espace Newtec

Les tags RFID utilisés dans l’espace Newtec ont la forme de petits disques (Figure 2) possédant les dimensions suivantes :

- d = | 15 mm
- h = | 3 mm
Ils seront utilisés pour des tâches spécifiques :
- Identification des palettes déposées dans une cellule
- Identification du contenu d’une palette déposée
- Identification du badge produit (Données de fabrication) Les tags RFID en question possèdent une mémoire de 106 bytes.

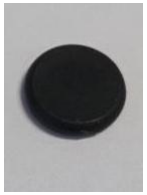
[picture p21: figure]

Figure 2 - Tag RFID de
l'espace Newtec

## 5 Contraintes

L’étudiant en charge de ce projet se doit de respecter plusieurs contraintes.

## 5.1 Structure des données stockées dans les tags RFID

Les tags RFID disposant d’une mémoire de 106 bytes, les données à y inscrire devront probablement être optimisées afin de garantir l’écriture intégrale de toutes les informations requises, à savoir :

- Palettes
- Identifiant de la palette (variant entre 1 et x)
- Contenu de la palette (allant jusqu’à 6 entrées différentes) comportant l’identification des bases¹

Paramètre | Contenu | Taille [octet]
Identifiant palette | Px | 2
Emplacement 1 | 1_TTT-XXXXXX-VV-R | 17
Emplacement 2 | 2_TTT-XXXXXX-VV-R | 17
Emplacement 3 | 3_TTT-XXXXXX-VV-R | 17
Emplacement 4 | 4_TTT-XXXXXX-VV-R | 17
Emplacement 5 | 5_TTT-XXXXXX-VV-R | 17
Emplacement 6 | 6_TTT-XXXXXX-VV-R | 17
Séparateur de paramètres | \n | 6
| Total : | 110
Tableau 1 - Taille mémoire pour stockage des informations liées aux palettes
Concernant les informations relatives aux palettes, il a été constaté qu’une optimisation est nécessaire afin de réduire l’espace mémoire utilisé.

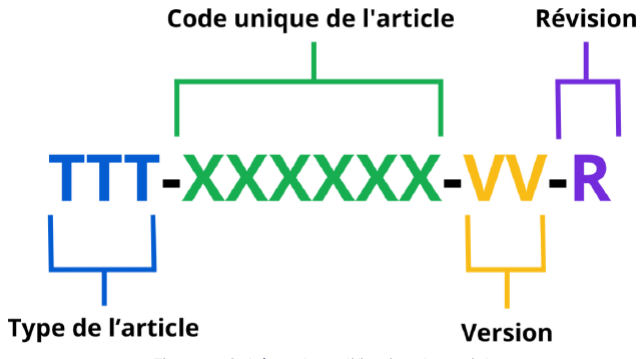
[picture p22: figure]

Figure 3 - Schéma de codification des articles

1

Il s’agit des variantes de badges décrites sur le wiki (table Item_type et se référer uniquement à « code ») : https://fkanbgwnz.preview.infomaniak.website/index.php?title=DB_Smart-Factory

- Badges
- Pseudonyme du client ayant commandé le badge
- Données de production
- Date, heure
- Identifiant des cellules ayant effectuée des opérations (fixé à 4 cellules actuellement)
- Identifiant de la palette utilisée pour la production
Paramètre | Contenu | Taille [octet]
Pseudonyme (allocation de 10 caractères) | QuentinRio | 10
Identifiant palette utilisée | Px | 2
Identifiant cellule 1 | C1 | 2
Date et heure cellule 1 | 00:00:00-00/00/00 | 17
Identifiant cellule 2 | C2 | 2
Date et heure cellule 2 | 00:00:00-00/00/00 | 17
Identifiant cellule 3 | C3 | 2
Date et heure cellule 3 | 00:00:00-00/00/00 | 17
Identifiant cellule 4 | C4 | 2
Date et heure cellule 4 | 00:00:00-00/00/00 | 17
Séparateur de paramètres | \n | 9
| Total : | 97
Tableau 2 - Taille mémoire pour stockage des informations liées aux badges
Concernant le contenu des badges, aucune optimisation n’est nécessaire. C’est un point positif, car les informations doivent rester clairement lisibles afin de faciliter la vérification des données de production.
Par souci d’évolutivité et afin de permettre l’ajout futur de nouvelles cellules, la mise en place d’un encodage reste préférable.

## 5.2 Communication et décodage des données au niveau PLC

Le langage de programmation utilisé dans les PLC de la Newtec, conforme à la norme IEC 61131-3, étant relativement bas niveau, l’encodage des données doit rester simple afin de faciliter leur décodage.
Le protocole de communication utilisé pour le prototype de lecture/écriture des tags RFID doit être compatible avec un PLC et facilement exploitable sur celui-ci et ne doit pas passer par un réseau internet (RS-232 par exemple).

## 5.3 Système embarqué

Les installations de l’espace Newtec fonctionnant en 24 V, le système embarqué doit être capable de supporter cette tension.
De plus, selon le protocole de communication utilisé, il sera nécessaire de mettre en place un convertisseur afin d’assurer la compatibilité de tension entre le PLC et le système embarqué.

## 5.4 Microcontrôleur

Le choix du microcontrôleur reste libre. Voici quelques propositions :

- PIC
- Arduino
- STM-32
L’utilisation d’un Raspberry Pi est interdite dû à l’encombrement de ceux-ci.

## 6 Travaux

Dans le cadre de ce projet, l’étudiant devra effectuer divers travaux.

## 6.1 Système embarqué

Mettre au point un système embarqué compact permettant la lecture et l’écriture de tags RFID
Le tout doit être compact et facilement montable dans les diverses cellules de l’espace Newtec. Il devra prendre place aux endroit suivants :
- Sous les empreintes de palettes se situant dans les diverses cellules permettant l’identification et la mise à jour du tag de chaque palette (Figure 4).
- Au niveau du convoyeur de la cellule de montage permettant la vérification du bon fonctionnement des badges RFID qui prendront place dans les badges assemblés (Figure 5).

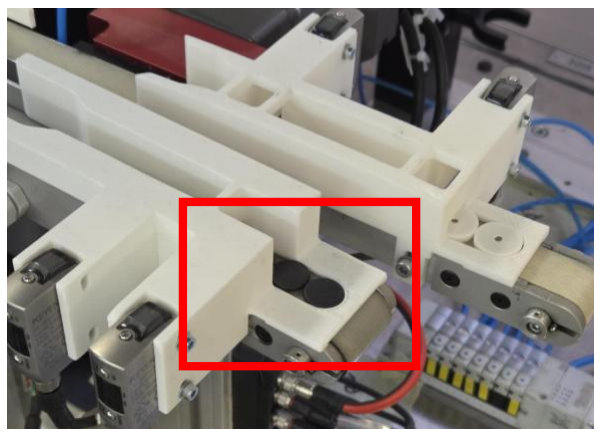
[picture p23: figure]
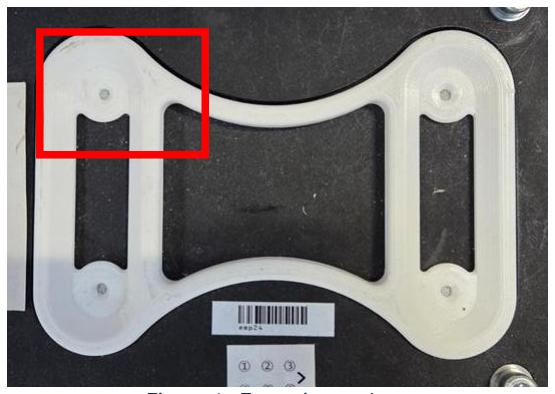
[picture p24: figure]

Figure 4 - Empreinte palette | Figure 5 - Convoyeur tags RFID de la cellule d'assemblage

(Optionnel)
Si l’étudiant possède une formation préalable en électronique, il pourra concevoir un circuit imprimé intégrant tous les composants nécessaires au bon fonctionnement du prototype sous une tension de 24 V. Sinon, cette partie sera sous-traitée.

## 6.2 Programmation

6.2.1 Librairie
Mettre au point une librairie offrant les fonctionnalités suivantes :
- Ecriture de tags RFID (fonction APPEND ou WRITE)
- Lecture de tags RFID
- Détecter si un tag RFID est défectueux ou non
- Encoder les données pour réduire la taille mémoire nécessaire
- L’encodage se doit d’être facilement décodable du côté PLC
- Démarrer des procédures de lecture et d’écriture en fonction des commandes transmises par l’automate.
- READ
- WRITE
- APPEND
- DELETE ALL
La librairie en question peut être divisée en plusieurs sous-librairies comportant la communication PLC et la gestion des tags RFID.
6.2.2 Programme
Le programme doit effectuer :
- Des tentatives de lectures cycliques sous ordre du PLC (une tentative de lecture toute les secondes par exemple)
- START_TAG_READ : | Démarrer la procédure de lecture
- STOP_TAG_READ : | Stopper la procedure de lecture
- Les résultats suivants sont attendus :
- Badge lu | : | Retourner son contenu au PLC
- Badge illisible | : | Retourner une erreur au PLC
- Badge HS² | : | Retourner une erreur au PLC
- Aucun badge | : | Ne rien faire
- Des écritures des tags RFID
- Sous ordre de l’automate avec les informations qu’il a fourni
- Utilisation d’un protocole de communication utilisable sur un PLC permettant de :
- Lui envoyer les données lues
- Ecrire les données envoyées depuis le PLC
- Définir la forme sous laquelle le PLC doit transmettre les données

2Un badge HS indique que malgré les tentatives de lecture aucun information n’est remontée. C’est comme si aucun badge n’était à proximité du lecteur. Dans ce cas, il faut pouvoir l’indiquer au PLC.

## 6.3 Circuit imprimé (optionnel)

Comme indiqué précédemment, si l’étudiant possède une formation en électronique, il devra concevoir un circuit imprimé capable de :

- Faire fonctionner l’électronique sous une tension d’alimentation de 24V
- Convertir les signaux du protocole de communication dans la tension adaptée pour le PLC dans les deux sens
- Intégrer le microcontrôleur choisi directement sur le PCB afin de réduire l’encombrement du système
- Fournir le schéma électronique et les fichiers nécessaires à la conception du circuit imprimé
- Concevoir un boîtier design et le plus compact possible afin de faciliter le montage du système embarqué aux emplacements désirés
S’il s’avère que l’étudiant n’est pas électronicien, fournir un prototype d’une taille raisonnable afin de le tester sur le terrain. La seule contrainte est :
- Faire fonctionner l’électronique sous une tension d’alimentation de 24V
- Convertir les signaux du protocole de communication dans la tension adaptée pour le PLC dans les deux sens

## 7 Adaptation du CDC

L’étudiant est libre d’ajouter ou de modifier des fonctionnalités en fonction de la faisabilité du projet.
Toutefois, chaque ajout ou modification doit être décrit de manière explicite et validé par l’encadrant ainsi que par le client.

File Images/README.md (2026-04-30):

Dossier contenant des images utilisés dans le projet.

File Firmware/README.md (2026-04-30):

Code source documenté du microcontrôleur, incluant la pile de communication et la librairie RFID.

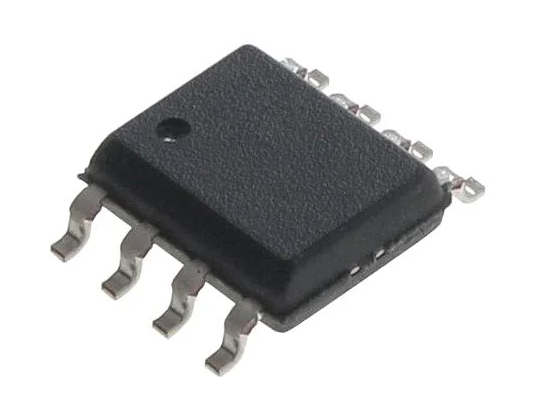
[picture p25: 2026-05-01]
Images/Hardware/MAX3485CSA+T.png

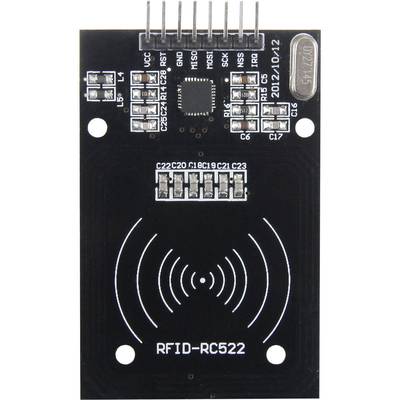
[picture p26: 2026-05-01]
Images/Hardware/SBC-RFID-RC522.jpg

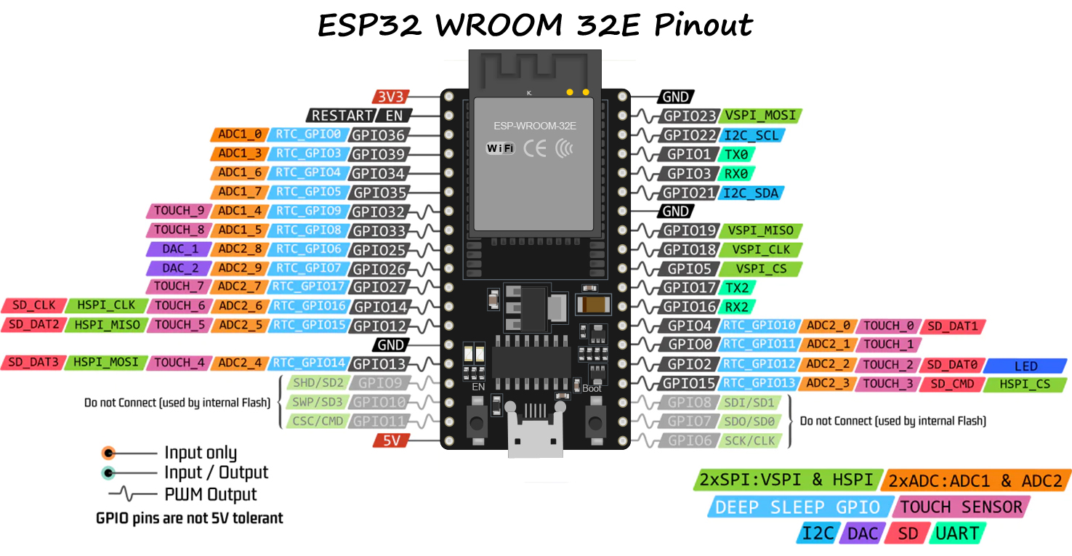
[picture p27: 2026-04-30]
Images/Hardware/esp32_pinout.webp

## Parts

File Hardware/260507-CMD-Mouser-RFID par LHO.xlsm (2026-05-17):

SECTION |  | Formulaire de Commande 17/05/26
I40 |  |  |  | Fournisseur
 |  |  | Raison sociale : | Mouser
Smart Factory |  |  | Rue : | Commande par internet
 |  |  |  | 0
 |  |  | NP/Localité : | 0 |  | 0.00
Utilisation | Consommables |  | Tél / Fax : | 0041 41 763 01 50 | Fax
Famille | Electronique |  | Email : | switzerland@mouser.com
N° inventaire | Réf.fournisseur | Libellé article | Quantité | Prix unitaire | Rabais | Prix
 | 581-REF1020471M050K | 470µF 50V | 1.00 | 0.57 |  | 0.57
 | 81-GRM319R61H475KA2D | 4.7μF 50V | 1.00 | 0.18 |  | 0.18
 | 187-CL31A106MBHNNNE | 10µF 50V | 1.00 | 0.21 |  | 0.21
 | 81-RDEC71H226MWK1H3B | 22µF 50V | 1.00 | 1.31 |  | 1.31
 | 241-BX36_R1_00001 | BX36_R1 | 1.00 | 0.29 |  | 0.29
 | 603-SMAJ28A/TR13 | SMAJ28A | 1.00 | 0.11 |  | 0.11
 | 392-CSANAVIDISPLAY1 | DM-OLED096-636 | 1.00 | 5.36 |  | 5.36
 | 859-LTST-C150AKT | LED | 2.00 | 0.11 |  | 0.22
 | 652-MFR050 | PTC 1A | 1.00 | 0.32 |  | 0.32
 | 179-TB0011-350-04GR | TB0011-350-04GR | 2.00 | 0.71 |  | 1.42
 | 710-7447060 | 300 µH | 1.00 | 2.06 |  | 2.06
 | 80-SS11VL-11050 | 5 mH | 1.00 | 1.49 |  | 1.49
 | 495-TSR1-2433E | TSR_1-2433E | 1.00 | 2.92 |  | 2.92
 | 179-SLW8747446ARAND | SLW-874744 | 1.00 | 0.41 |  | 0.41
 | 713-113991114 | XIAO-ESP32-C6-DIP | 1.00 | 5.94 |  | 5.94
 | 700-MAX3485CSAT | MAX3485CSA_T | 1.00 | 5.07 |  | 5.07
 | 652-MOV-20D470K | 20D470K | 1.00 | 0.67 |  | 0.67
 | 538-146153-0100 | Antennes plates | 5.00 | 1.96 |  | 9.80
 |  |  |  |  |  | 0.00
 |  |  |  |  |  | 0.00
Remarque : | Indiquez d'un X le matériel a inventorier et utilisez la case pour indiquer le numéro d'inventaire existant. |  |  | Total HT |  | 38.35
Etabli Par : |  | Date Création |  | Rabais Ecole |  | 0.00
LHO | Hofer | 2026-05-17
Visa Coordinateur |  | Visa Direction |  | Frais de port
 |  |  |  | TVA | 0.0% | 0.00
 |  |  |  | Total CHF |  | 38.35
 |  |  | TRUE
Nom de fichier : | https://divtec.sharepoint.com/groupe_industrie40/Documents%20partages/01%20Gestion%20Mat%C3%A9riel/20-Commandes/CMD%202025/250124-CMD-Mouser-Consommables Automatique par AMO- I1-.XLS

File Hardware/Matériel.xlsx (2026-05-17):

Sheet: Liste de matériels (prototy (2)
Reference | Nom | Valeur | Ref Mouser | Ref fab. | datasheet | Fournisseur | prix | nombre | somme
C1 | Condensateur électrolytique | 470µF | 581-REF1020471M050K | REF1020471M050K (https://www.mouser.ch/ProductDetail/KYOCERA-AVX/REF1020471M050K) | ./Datasheets/Condensateur 470 uF elec - ref-series.pdf | Mouser | 0.57 CHF | 1 | 0.57 CHF
C2 | Condensateur ceram | 4.7μF | 81-GRM319R61H475KA2D | GRM319R61H475KA12D (https://www.mouser.ch/ProductDetail/Murata-Electronics/GRM319R61H475KA12D?qs=O5cugoO6nwcJ%2FK8D7TJIYw%3D%3D) | ./Datasheets/Condensateur 4,7 uF ceram - GRM319R61H475KA12_01A.pdf | Mouser | 0.18 CHF | 1 | 0.18 CHF
C3 | Condensateur ceram | 10µF | 187-CL31A106MBHNNNE | CL31A106MBHNNNE (https://www.mouser.ch/ProductDetail/Samsung-Electro-Mechanics/CL31A106MBHNNNE?qs=vLWxofP3U2ynwxdpGjlUyw%3D%3D) | ./Datasheets/DataSheet_CL31A106MBHNNN_20260505.pdf | Mouser | 0.21 CHF | 1 | 0.21 CHF
C4 | Condensateur ceram | 22µF | 81-RDEC71H226MWK1H3B | RDEC71H226MWK1H03B (https://www.mouser.ch/ProductDetail/Murata-Electronics/RDEC71H226MWK1H03B) | ./Datasheets/Condensateur 22 uF ceram - GRM188R61A226ME15-02A.pdf | Mouser | 1.31 CHF | 1 | 1.31 CHF
D1 | Diode Schottky | BX36_R1 | 241-BX36_R1_00001 | BX36_R1_00001 (https://www.mouser.ch/ProductDetail/Panjit/BX36_R1_00001?qs=sPbYRqrBIVmjqOTXjM%2FXjA%3D%3D) | ./Datasheets/Diode - BX36_R1_00001.pdf | Mouser | 0.29 CHF | 1 | 0.29 CHF
D2 | diode TVS | SMAJ28A | 603-SMAJ28A/TR13 | SMAJ28A/TR13 (https://eu.mouser.com/ProductDetail/YAGEO/SMAJ28A-TR13?qs=PzGy0jfpSMsLoNBGbvsUFQ%3D%3D) | ./Datasheets/SMAJ_1.pdf | Mouser | 0.11 CHF | 1 | 0.11 CHF
E1 | Écran OLED | DM-OLED096-636 | 392-CSANAVIDISPLAY1 | DST-015 (OLED SSD1305) (https://www.mouser.ch/ProductDetail/ANAVI-Technology/CS-ANAVI-DISPLAY-1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) |  | Mouser | 5.36 CHF | 1 | 5.36 CHF
E2, E3 | LED (ambre) | LED | 859-LTST-C150AKT | LTST-C150AKT (https://www.mouser.ch/ProductDetail/LITEON/LTST-C150AKT?qs=osRiLXwIJd0WBpdBnGWjYQ%3D%3D) | ./Datasheets/AmberLed - LTST-C150AKT.pdf | Mouser | 0.11 CHF | 2 | 0.22 CHF
F1 | Fusible réarmable | PTC 1A | 652-MFR050 | MF-R050 (https://www.mouser.ch/ProductDetail/Bourns/MF-R050?qs=A6omU7D3gEWzJRzbTsuTwA%3D%3D) | ./Datasheets/PTC.pdf | Mouser | 0.32 CHF | 1 | 0.32 CHF
J1, J2 | Bornier | TB0011-350-04GR | 179-TB0011-350-04GR | TB0011-350-04GR (https://eu.mouser.com/ProductDetail/Same-Sky/TB0011-350-04GR?qs=PBDs2xEllI8Qb4YnuFeAHQ%3D%3D) | ./Datasheets/TB0011-350-04GR.pdf | Mouser | 0.71 CHF | 2 | 1.42 CHF
L1 | inductance torique | 300 µH | 710-7447060 | 7447060 (https://www.mouser.fr/ProductDetail/Wurth-Elektronik/7447060?qs=sGAEpiMZZMv126LJFLh8y7bZMRioh4ww7S2La6H8kL0%3D) | ./Datasheets/induct - 7447060.pdf | Mouser | 2.06 CHF | 1 | 2.06 CHF
L2 | inductance de mode commun | 5 mH | 80-SS11VL-11050 | SS11VL-11050 (https://www.mouser.fr/ProductDetail/KEMET/SS11VL-11050?qs=EU6FO9ffTwcryP%252B%2F%252BYgxUg%3D%3D) | ./Datasheets/induct - SS11VL_11050.pdf | Mouser | 1.49 CHF | 1 | 1.49 CHF
PS1 | Alimentation | TSR_1-2433E | 495-TSR1-2433E | TSR 1-2433E (https://eu.mouser.com/ProductDetail/TRACO-Power/TSR-1-2433E?qs=vmHwEFxEFR9haWIzn8wG3A%3D%3D) | ./Datasheets/TSR 1-2433E - tsr1e_datasheet.pdf | Mouser | 2.92 CHF | 1 | 2.92 CHF
S1 | Switch horizontal | SLW-874744 | 179-SLW8747446ARAND | SLW-874744-6A-RA-N-D (https://www.mouser.ch/ProductDetail/Same-Sky/SLW-874744-6A-RA-N-D?qs=IKkN%2F947nfCTUBrapEhl3w%3D%3D) | ./Datasheets/slw_874744_6a_ra_n_d.pdf | Mouser | 0.41 CHF | 1 | 0.41 CHF
U1 | ESP32 | XIAO-ESP32-C6-DIP | 713-113991114 | XIAO-ESP32-S3 (https://www.mouser.ch/ProductDetail/Seeed-Studio/113991114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) | ./Datasheets/esp32-s3.pdf | Mouser | 5.94 CHF | 1 | 5.94 CHF
U2 | Module RFID | RFID-RC522 |  | Module SBC-RFID-RC522 |  | Inconnu | 8.00 CHF | 1 | 8.00 CHF
U3 | transceiver UART | MAX3485CSA_T | 700-MAX3485CSAT | MAX3485CSA+T (https://www.mouser.ch/ProductDetail/Analog-Devices-Maxim-Integrated/MAX3485CSA%2bT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) | ./Datasheets/MAX3483_MAX3491.pdf | Mouser | 5.07 CHF | 1 | 5.07 CHF
RV1 | Varistance | 20D470K | 652-MOV-20D470K | MOV-20D470K (https://www.mouser.fr/ProductDetail/Bourns/MOV-20D470K?qs=CQ3B1E%252BbPs3c5MjsJHIexQ%3D%3D) | ./Datasheets/Varistance - mov20d.pdf | Mouser | 0.67 CHF | 1 | 0.67 CHF
J3 | Antenne | 50ohms | 538-146153-0100 | 146153-0100 |  | Mouser | 1.96 CHF | 1 | 1.96 CHF
 |  |  |  |  |  |  |  | total | 36.55 CHF

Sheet: Liste de matériels (prototype)
 | Reference | Nom | Valeur | Ref fab. | datasheet | Fournisseur | prix | nombre | somme
 | C1 | Condensateur électrolytique | 470µF | REF1020471M050K (https://www.mouser.ch/ProductDetail/KYOCERA-AVX/REF1020471M050K) | ./Datasheets/Condensateur 470 uF elec - ref-series.pdf | Mouser | 0.57 CHF | 1 | 0.57 CHF
 | C2 | Condensateur ceram | 4.7μF | GRM319R61H475KA12D (https://www.mouser.ch/ProductDetail/Murata-Electronics/GRM319R61H475KA12D?qs=O5cugoO6nwcJ%2FK8D7TJIYw%3D%3D) | ./Datasheets/Condensateur 4,7 uF ceram - GRM319R61H475KA12_01A.pdf | Mouser | 0.18 CHF | 1 | 0.18 CHF
 | C3 | Condensateur ceram | 10µF | CL31A106MBHNNNE (https://www.mouser.ch/ProductDetail/Samsung-Electro-Mechanics/CL31A106MBHNNNE?qs=vLWxofP3U2ynwxdpGjlUyw%3D%3D) | ./Datasheets/DataSheet_CL31A106MBHNNN_20260505.pdf | Mouser | 0.21 CHF | 1 | 0.21 CHF
 | C4 | Condensateur ceram | 22µF | RDEC71H226MWK1H03B (https://www.mouser.ch/ProductDetail/Murata-Electronics/RDEC71H226MWK1H03B) | ./Datasheets/Condensateur 22 uF ceram - GRM188R61A226ME15-02A.pdf | Mouser | 1.31 CHF | 1 | 1.31 CHF
 | D1 | Diode Schottky | BX36_R1 | BX36_R1_00001 (https://www.mouser.ch/ProductDetail/Panjit/BX36_R1_00001?qs=sPbYRqrBIVmjqOTXjM%2FXjA%3D%3D) | ./Datasheets/Diode - BX36_R1_00001.pdf | Mouser | 0.29 CHF | 1 | 0.29 CHF
 | D2 | diode TVS | SMAJ28A | SMAJ28A/TR13 (https://eu.mouser.com/ProductDetail/YAGEO/SMAJ28A-TR13?qs=PzGy0jfpSMsLoNBGbvsUFQ%3D%3D) | ./Datasheets/SMAJ_1.pdf | Mouser | 0.11 CHF | 1 | 0.11 CHF
 | E1 | Écran OLED | DM-OLED096-636 | DST-015 (OLED SSD1305) (https://www.mouser.ch/ProductDetail/ANAVI-Technology/CS-ANAVI-DISPLAY-1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) |  | Mouser | 5.36 CHF | 1 | 5.36 CHF
 | E2, E3 | LED (ambre) | LED | LTST-C150AKT (https://www.mouser.ch/ProductDetail/LITEON/LTST-C150AKT?qs=osRiLXwIJd0WBpdBnGWjYQ%3D%3D) | ./Datasheets/AmberLed - LTST-C150AKT.pdf | Mouser | 0.11 CHF | 2 | 0.22 CHF
 | F1 | Fusible réarmable | PTC 1A | MF-R050 (https://www.mouser.ch/ProductDetail/Bourns/MF-R050?qs=A6omU7D3gEWzJRzbTsuTwA%3D%3D) | ./Datasheets/PTC.pdf | Mouser | 0.32 CHF | 1 | 0.32 CHF
 | J1, J2 | Bornier | TB0011-350-04GR | TB0011-350-04GR (https://eu.mouser.com/ProductDetail/Same-Sky/TB0011-350-04GR?qs=PBDs2xEllI8Qb4YnuFeAHQ%3D%3D) | ./Datasheets/TB0011-350-04GR.pdf | Mouser | 0.71 CHF | 2 | 1.42 CHF
 | L1 | inductance torique | 300 µH | 7447060 (https://www.mouser.fr/ProductDetail/Wurth-Elektronik/7447060?qs=sGAEpiMZZMv126LJFLh8y7bZMRioh4ww7S2La6H8kL0%3D) | ./Datasheets/induct - 7447060.pdf | Mouser | 2.06 CHF | 1 | 2.06 CHF
 | L2 | inductance de mode commun | 5 mH | SS11VL-11050 (https://www.mouser.fr/ProductDetail/KEMET/SS11VL-11050?qs=EU6FO9ffTwcryP%252B%2F%252BYgxUg%3D%3D) | ./Datasheets/induct - SS11VL_11050.pdf | Mouser | 1.49 CHF | 1 | 1.49 CHF
 | PS1 | Alimentation | TSR_1-2433E | TSR 1-2433E (https://eu.mouser.com/ProductDetail/TRACO-Power/TSR-1-2433E?qs=vmHwEFxEFR9haWIzn8wG3A%3D%3D) | ./Datasheets/TSR 1-2433E - tsr1e_datasheet.pdf | Mouser | 2.92 CHF | 1 | 2.92 CHF
Atelier ELT | R1, R5 | Résistance | 68 R | AC1206JR-0768RL (https://www.mouser.ch/ProductDetail/YAGEO/AC1206JR-0768RL?qs=sGAEpiMZZMtlubZbdhIBIH9nMdKz1PS4cbS68O8anDU%3D) | ./Datasheets/68R - PYU_AC_51_ROHS_L.pdf | Mouser | 0.08 CHF | 2 | 0.16 CHF
 | R2 | Résistance | 120 R | RC1206JR-07120RL (https://www.mouser.ch/ProductDetail/YAGEO/RC1206JR-07120RL) | ./Datasheets/120R - YAGEO_PYu_RC_Group_51_RoHS_L_12.pdf | Mouser | 0.08 CHF | 1 | 0.08 CHF
 | R3, R4 | Résistance | 4k7 | RC1206JR-104K7L (https://www.mouser.ch/ProductDetail/YAGEO/RC1206JR-104K7L) | ./Datasheets/120R - YAGEO_PYu_RC_Group_51_RoHS_L_12.pdf | Mouser | 0.08 CHF | 2 | 0.16 CHF
 | S1 | Switch horizontal | SLW-874744 | SLW-874744-6A-RA-N-D (https://www.mouser.ch/ProductDetail/Same-Sky/SLW-874744-6A-RA-N-D?qs=IKkN%2F947nfCTUBrapEhl3w%3D%3D) | ./Datasheets/slw_874744_6a_ra_n_d.pdf | Mouser | 0.41 CHF | 1 | 0.41 CHF
 | U1 | ESP32 | XIAO-ESP32-C6-DIP | XIAO-ESP32-S3 (https://www.mouser.ch/ProductDetail/Seeed-Studio/113991114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) | ./Datasheets/esp32-s3.pdf | Mouser | 5.94 CHF | 1 | 5.94 CHF
 | U2 | Module RFID | RFID-RC522 | Module SBC-RFID-RC522 |  | Inconnu | 8.00 CHF | 1 | 8.00 CHF
 | U3 | transceiver UART | MAX3485CSA_T | MAX3485CSA+T (https://www.mouser.ch/ProductDetail/Analog-Devices-Maxim-Integrated/MAX3485CSA%2bT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) | ./Datasheets/MAX3483_MAX3491.pdf | Mouser | 5.07 CHF | 1 | 5.07 CHF
 | RV1 | Varistance | 20D470K | MOV-20D470K (https://www.mouser.fr/ProductDetail/Bourns/MOV-20D470K?qs=CQ3B1E%252BbPs3c5MjsJHIexQ%3D%3D) | ./Datasheets/Varistance - mov20d.pdf | Mouser | 0.67 CHF | 1 | 0.67 CHF
 |  |  |  |  |  |  |  | total | 36.95 CHF

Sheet: XIAO ESP32
 | TOUCH1 | A0 | GPIO1 | D0 | XIAO ESP32-S3 | 5V |  |  |  |  | dual-core 240MHz
 | TOUCH2 | A1 | GPIO2 | D1 |  | GND |  |  |  |  | 8MB PSRAM
 | TOUCH3 | A2 | GPIO3 | D2 |  | 3V3 |  |  |  |  | 8MB Flash
 | TOUCH4 | A3 | GPIO4 | D3 |  | D10 | GPIO9 | A10 | MOSI | TOUCH9 | https://wiki.seeedstudio.com/xiao_esp32s3_getting_started/
TOUCH5 | SDA | A4 | GPIO5 | D4 |  | D9 | GPIO8 | A9 | MISO | TOUCH8
TOUCH6 | SCL | A5 | GPIO6 | D5 |  | D8 | GPIO7 | A8 | SCK | TOUCH7
 |  | TX | GPIO43 | D6 |  | D7 | GPIO44 | RX
LP_GPIO1 |  | A0 | GPIO0 | D0 | XIAO ESP32-C6 | 5V
LP_GPIO1 |  | A1 | GPIO1 | D1 |  | GND |  |  |  |  | dual-core 160MHz
LP_GPIO2 |  | A2 | GPIO2 | D2 |  | 3V3 |  |  |  |  | 512KB SRAM
SDIO_DATA1 |  |  | GPIO21 | D3 |  | D10 | GPIO18 |  | MOSI | SDIO_CMD | 4 MB Flash
SDIO_DATA2 | SDA |  | GPIO22 | D4 |  | D9 | GPIO20 |  | MISO | SDIO_DATA0 | https://wiki.seeedstudio.com/xiao_esp32C6_getting_started/
SDIO_DATA3 | SCL |  | GPIO23 | D5 |  | D8 | GPIO19 |  | SCK | SDIO_CLK
 |  | TX | GPIO16 | D6 |  | D7 | GPIO17 | RX

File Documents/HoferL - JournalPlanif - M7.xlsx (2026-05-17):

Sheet: Journal
date | Temps | type de travail | description | type de travail | somme
22.04.2026 | 7:00:00 | Documentation | Création du cahier des charges | Cours | 0.0 H | 0% | Plannification | 2.5H
27.04.2026 | 2:30:00 | Plannification | Création de la plannification global du projet avec les différents sprints | Plannification | 2.5 H | 4.6875% | Recherche | 7.5H
30.04.2026 | 3:00:00 | Documentation | Réedition du cahier des charges | Recherche | 7.5 H | 14.0625% | Documentation | 22.33333333H
30.04.2026 | 2:00:00 | Documentation | Création du dépot GitHub, arboressance du projet et README | Documentation | 22.3 H | 41.875% | Tests | 1H
30.04.2026 | 2:00:00 | Recherche | Recherche de protocol de comm. + recherche sur le projet | Programmation | 0.0 H | 0% | Prototypage | 20H
01.05.2026 | 3:00:00 | Recherche | Recherche de composants | Tests | 1.0 H | 1.875% | Somme | 53.33333333H
01.05.2026 | 3:00:00 | Documentation | Documentation des composant séléctionnés | Prototypage | 20.0 H
01.05.2026 | 1:00:00 | Recherche | Recherche des composant chez distributeur | Présentation | 0.0 H | 0%
01.05.2026 | 0:30:00 | Documentation | Création d'une liste de composant avec prix | Somme | 53.3 H | 100%
2026-05-04 | 2:00:00 | Prototypage | Ajout des différentes librairies sur KiCad
2026-05-04 | 4:00:00 | Prototypage | Création d'une librairie de composants pour le projet | Temps restant | 21.7 H
2026-05-04 | 1:30:00 | Prototypage | Circuit d'alimentation avec schéma + liste de matériel
2026-05-05 | 3:00:00 | Prototypage | Refonte de l'alimentation + norme EN 55032 Classe B
2026-05-05 | 0:20:00 | Documentation | Ajout de toutes les documentation + prix des composants
2026-05-06 | 1:30:00 | Documentation | Documentation technique du schéma du prototype
2026-05-06 | 8:00:00 | Prototypage | Placement des composant, routage sur le PCB du prototype
2026-05-07 | 2:00:00 | Documentation | Documentation de l'implémentation du prototypage
2026-05-07 | 1:30:00 | Prototypage | Discution avec JET (ELT2) pour l'impression de la carte
2026-05-07 | 1:00:00 | Tests | Correction de la violation de la RDC.
2026-05-07 | 1:30:00 | Recherche | Recherche de solution pour le software
2026-05-07 | 2:30:00 | Documentation | Documentation des différents choix pour le software
2026-05-17 | 0:30:00 | Documentation | Commande mouser

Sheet: SommeParJours
date | somme
22.04.2026 | 7:00:00
27.04.2026 | 2:30:00
30.04.2026 | 7:00:00
01.05.2026 | 7:30:00
2026-05-04 | 7:30:00
2026-05-05 | 3:20:00
2026-05-06 | 9:30:00
2026-05-07 | 8:30:00
2026-05-17 | 0:30:00
 | 0:00:00
 | 0:00:00
 | 0:00:00
 | 0:00:00
 | 0:00:00
 | 0:00:00
 | 0:00:00
 | 0:00:00
 | 0:00:00
 | 0:00:00
 | 0:00:00
 | 0:00:00
 | 0:00:00
 | 0:00:00
 | 0:00:00
 | 0:00:00 | 0:00:00
 | 0:00:00 | 0:00:00
 |  | 0:00:00
 |  | 0:00:00
 |  | 0:00:00
 |  | 0:00:00
 |  | 0:00:00
 |  | 0:00:00
 |  | 0:00:00
 |  | 0:00:00
 |  | 0:00:00
 |  | 0:00:00
 |  | 0:00:00
 |  | 0:00:00
 |  | 0:00:00
 |  | 0:00:00
 |  | 0:00:00
 |  | 0:00:00
 |  | 0:00:00
 |  | 0:00:00
 |  | 0:00:00
 |  | 0:00:00
 |  | 0:00:00
 |  | 0:00:00
 |  | 0:00:00
 |  | 0:00:00
 |  | 0:00:00
 |  | 0:00:00
 |  | 0:00:00
 |  | 0:00:00
 |  | 0:00:00
 |  | 0:00:00
 |  | 0:00:00
 |  | 0:00:00
 |  | 0:00:00
 |  | 0:00:00
 |  | 0:00:00
 |  | 0:00:00
 |  | 0:00:00
 |  | 0:00:00
 |  | 0:00:00
 |  | 0:00:00
 |  | 0:00:00
 |  | 0:00:00
 |  | 0:00:00
 |  | 0:00:00
 |  | 0:00:00
 |  | 0:00:00
 |  | 0:00:00
 |  | 0:00:00
 |  | 0:00:00
 |  | 0:00:00
 |  | 0:00:00
 |  | 0:00:00
 |  | 0:00:00
 |  | 0:00:00
 |  | 0:00:00
 |  | 0:00:00
 |  | 0:00:00
 |  | 0:00:00
 |  | 0:00:00
 |  | 0:00:00
 |  | 0:00:00
 |  | 0:00:00
 |  | 0:00:00
 |  | 0:00:00
 |  | 0:00:00
 |  | 0:00:00
 |  | 0:00:00
 |  | 0:00:00
 |  | 0:00:00
 |  | 0:00:00
 |  | 0:00:00
 |  | 0:00:00
 |  | 0:00:00
 |  | 0:00:00
 |  | 0:00:00
 |  | 0:00:00
 |  | 0:00:00
 |  | 0:00:00
 |  | 0:00:00
 |  | 0:00:00
 |  | 0:00:00
 |  | 0:00:00
 |  | 0:00:00
 |  | 0:00:00
 |  | 0:00:00
 |  | 0:00:00
 |  | 0:00:00

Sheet: Plannification
Phases | Tâche | 22.04.2026 | 27.04.2026 | 30.04.2026 | 06.05.2026 | 07.05.2026 | 11.05.2026 | 18.05.2026 | 22.05.2026 | 28.05.2026 | 01.06.2026 | 03.06.2026 | 08.06.2026 | 11.06.2026 | 12.06.2026 | 15.06.2026 | 17.06.2026 | 18.06.2026
H |  | 7 | 4 | 4 | 7 | 5 | 7 | 0 | 0 | 5 | 4 | 7 | 4 | 5 | 0 | 4 | 7 | 5
S | Sprints | Conception Matérielle (27h) |  |  |  |  | Développement Logiciel (16h) |  |  |  |  |  | Tests, Validation et Livrables (27h) |  |  |  |  |  | 75
Documentation | Plannification |  |  |  |  |  |  |  |  |  |  |  |  |  |  |  |  |  | Absence : | 18.05.26 à 22.05.26 : IFA Formation
 | Cahier des charges
 | Plannification
 | Documentation technique
Conception | Choix des composants
 | Schéma électronique
 | Implémentation
 | Tests fonctionnements prototype
Développement logiciel | Arch. de communication (API et automate)
 | Arch trammes
 | Schéma de données (stockage)
 | Librairie RFID
 | Dév. logiciel embarqué
Tests, Validation et Livrables | Tests globaux
 | Debug
 | Schéma électrique final + PCB
 | Impression PCB + assemblage
 | Création boitier
 | Création présentation
 | Finalisation des livrables (archive du projet)
Jalons | Présentation
 |  |  |  |  |  |  |  |  |  |  |  |  |  |  |  |  |  |  | Planifié
 | Remise du travail complet |  |  |  |  |  |  |  |  |  |  |  |  |  |  |  |  |  | Dans les temps
 |  |  |  |  |  |  |  |  |  |  |  |  |  |  |  |  |  |  | Retard
 |  |  |  |  |  |  |  |  |  |  |  |  |  |  |  |  |  |  | 2026-06-12 | réédition des documents
 |  |  |  |  |  |  |  |  |  |  |  |  |  |  |  |  |  |  | 17 | présentation
 |  |  |  |  |  |  |  |  |  |  |  |  |  |  |  |  |  |  | 18 | finaliser projet

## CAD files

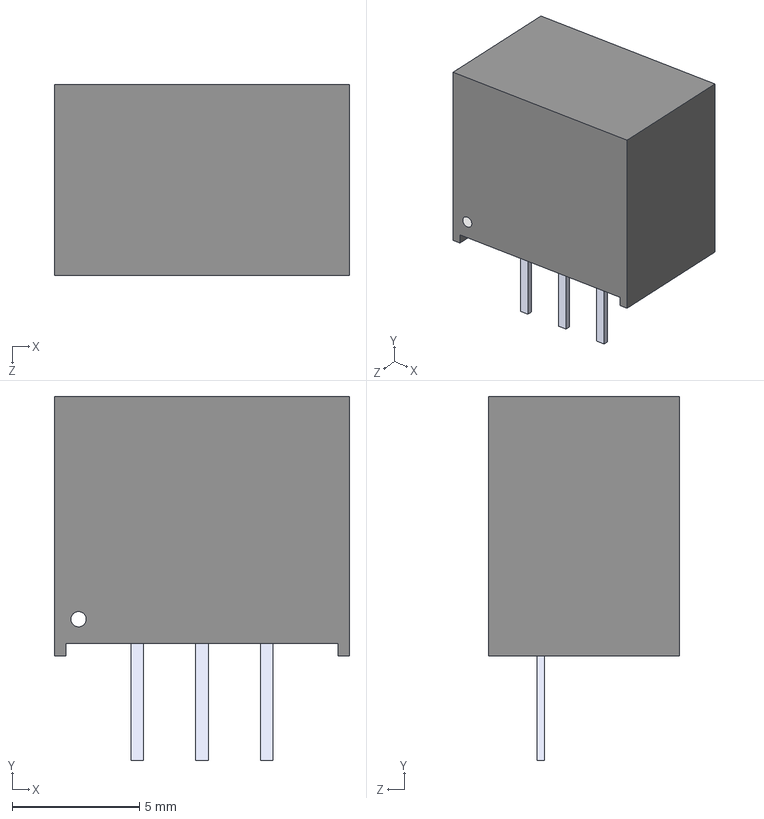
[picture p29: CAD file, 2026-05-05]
Hardware/RFID_ProjetKicad/LibrairiesExternes/RFID_3D/TSR_1-2433E.step
11.6 x 14.3 x 7.50 mm

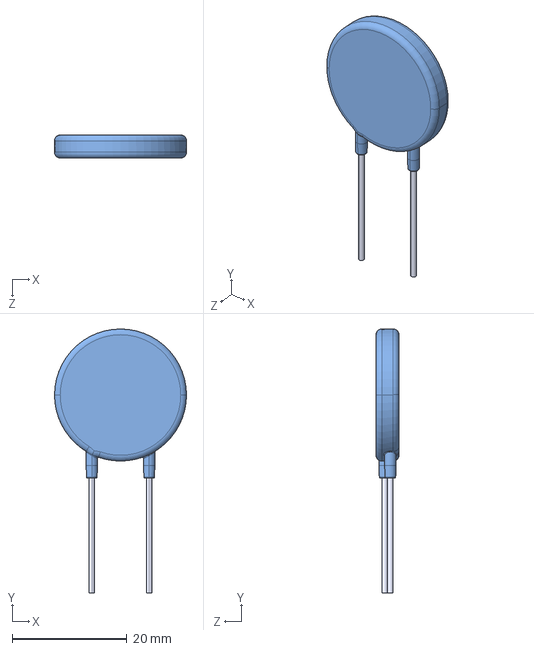
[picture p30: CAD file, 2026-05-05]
Hardware/RFID_ProjetKicad/LibrairiesExternes/RFID_3D/MOV-20D470KTR.STEP
23.0 x 46.0 x 4.00 mm

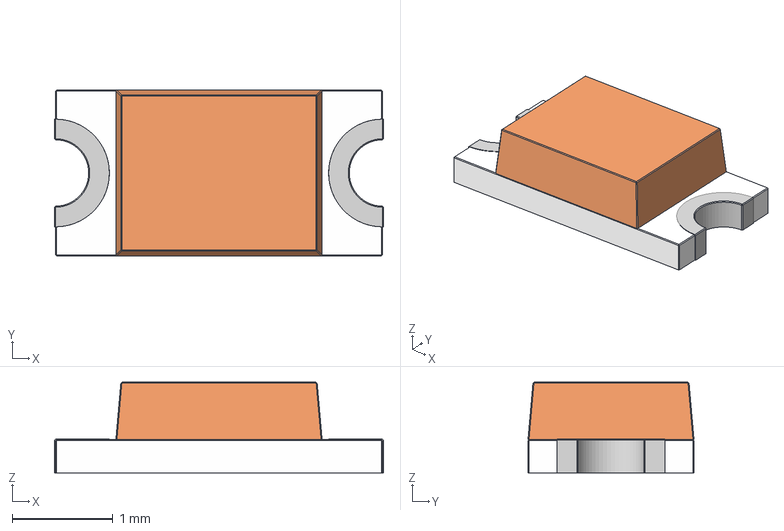
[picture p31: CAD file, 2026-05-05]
Hardware/RFID_ProjetKicad/LibrairiesExternes/RFID_3D/LED_1206_Orange.stp
3.27 x 1.65 x 0.9 mm

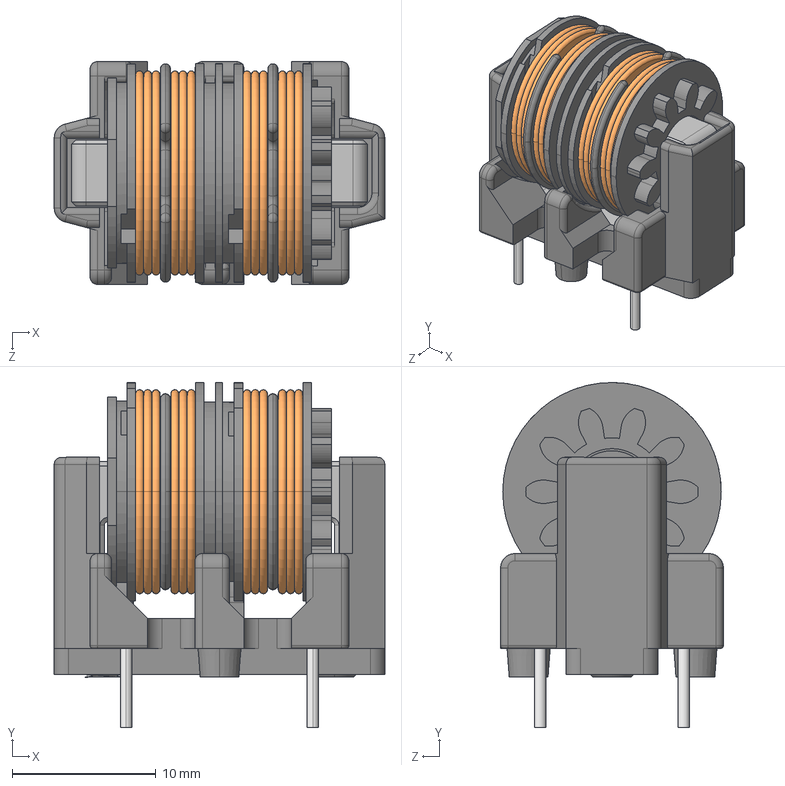
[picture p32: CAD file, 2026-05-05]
Hardware/RFID_ProjetKicad/LibrairiesExternes/RFID_3D/SS11VL-11050.step
23.0 x 24.0 x 15.5 mm

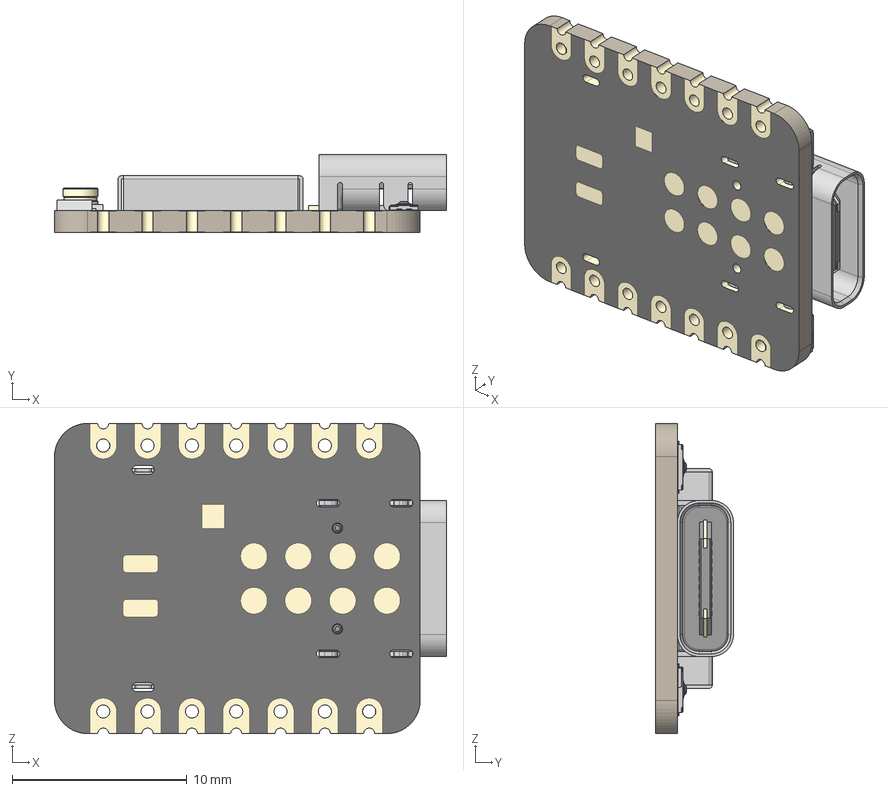
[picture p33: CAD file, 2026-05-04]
Hardware/RFID_ProjetKicad/LibrairiesExternes/RFID_3D/Seeed Studio XIAO ESP32-C6.step
22.5 x 4.46 x 17.8 mm
BOSS-EXTRUDE14_8_
BOSS-EXTRUDE7_4_
BOSS-EXTRUDE7_3_
BOSS-EXTRUDE14_4_
BOSS-EXTRUDE14_2_
BOSS-EXTRUDE14_11_
BOSS-EXTRUDE7_7_
BOSS-EXTRUDE14_9_
BOSS-EXTRUDE14_3_
BOSS-EXTRUDE14_7_
MIRROR2
BOSS-EXTRUDE14_5_
BOSS-EXTRUDE14_12_
BOSS-EXTRUDE7_8_
BOSS-EXTRUDE7_1_
BOSS-EXTRUDE14_10_
BOSS-EXTRUDE7_9_
BOSS-EXTRUDE14_6_
BOSS-EXTRUDE14_1_
BOSS-EXTRUDE7_6_
BOSS-EXTRUDE7_2_
CUT-EXTRUDE5
BOSS-EXTRUDE7_5_
U.FL Connector v1
Shield
SKTAAAE010 x 2
KH5220-A36 (Ceramic Antenna) v2

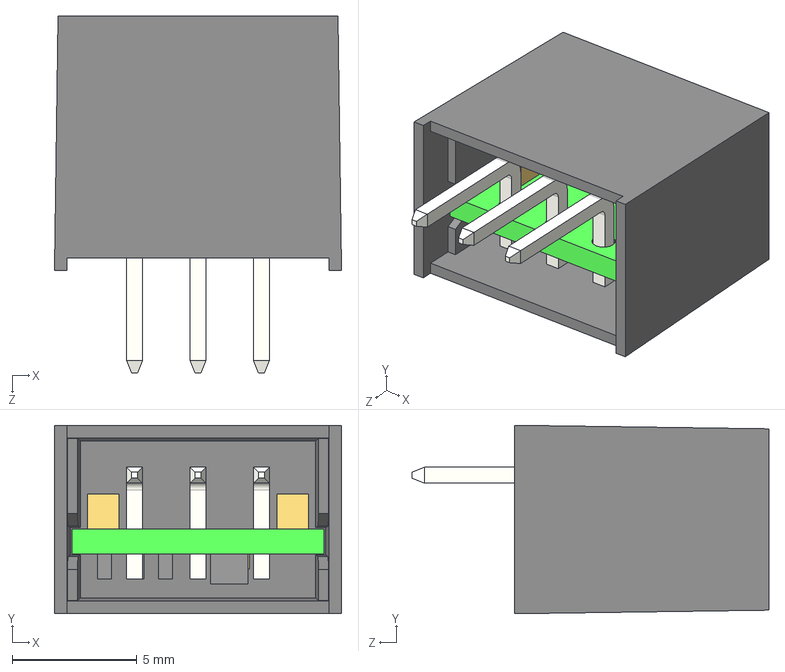
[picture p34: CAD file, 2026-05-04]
Hardware/RFID_ProjetKicad/LibrairiesExternes/RFID_3D/R-78K2.5-0.5.step
11.5 x 7.55 x 14.3 mm

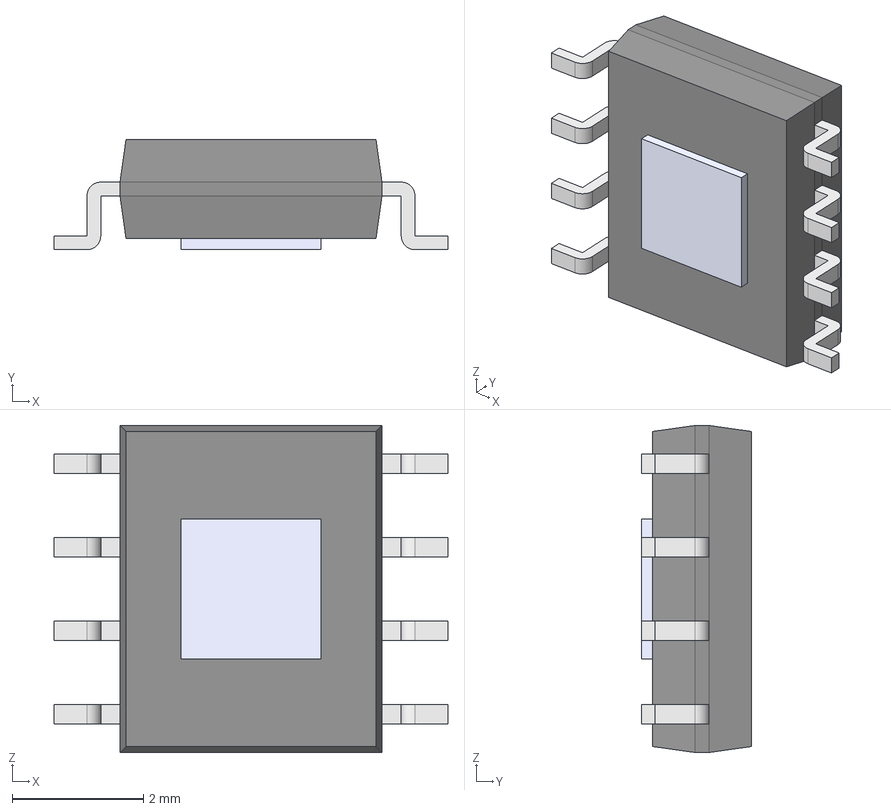
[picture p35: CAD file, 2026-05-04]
Hardware/RFID_ProjetKicad/LibrairiesExternes/RFID_3D/MAX3485CSA_T.step
6.00 x 1.68 x 4.98 mm
Body001 (Mirror #1) x 4
XY-plane x 12
X-axis x 12

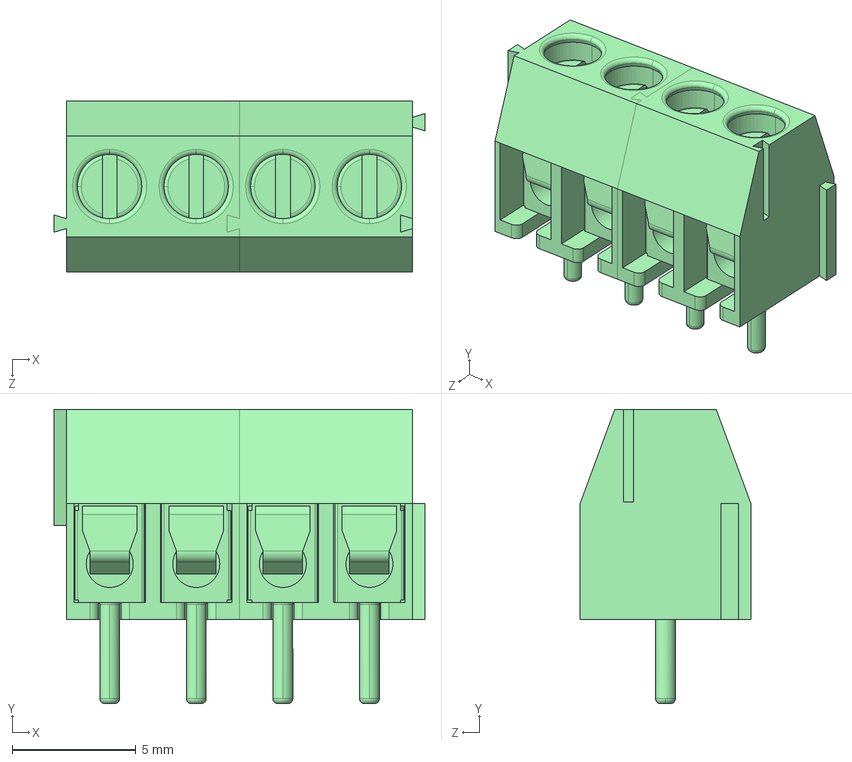
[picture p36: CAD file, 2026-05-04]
Hardware/RFID_ProjetKicad/LibrairiesExternes/RFID_3D/TB0011-350-04GR.step
15.0 x 11.9 x 6.90 mm

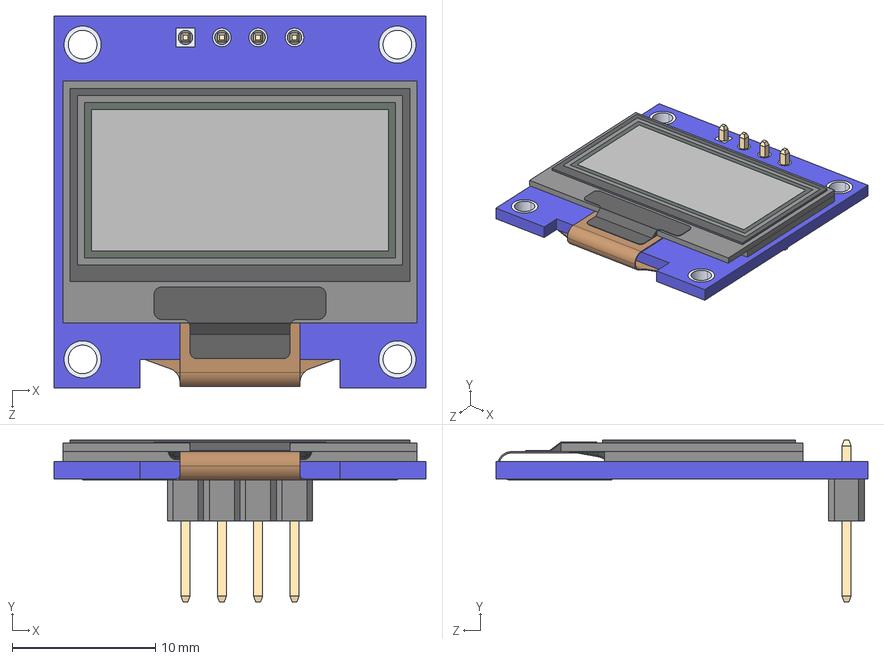
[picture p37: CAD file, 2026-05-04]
Hardware/RFID_ProjetKicad/LibrairiesExternes/RFID_3D/DM-OLED096-636.step
26.0 x 11.3 x 26.0 mm
DM-OLED096-636_Module
DM-OLED096-636_Panel

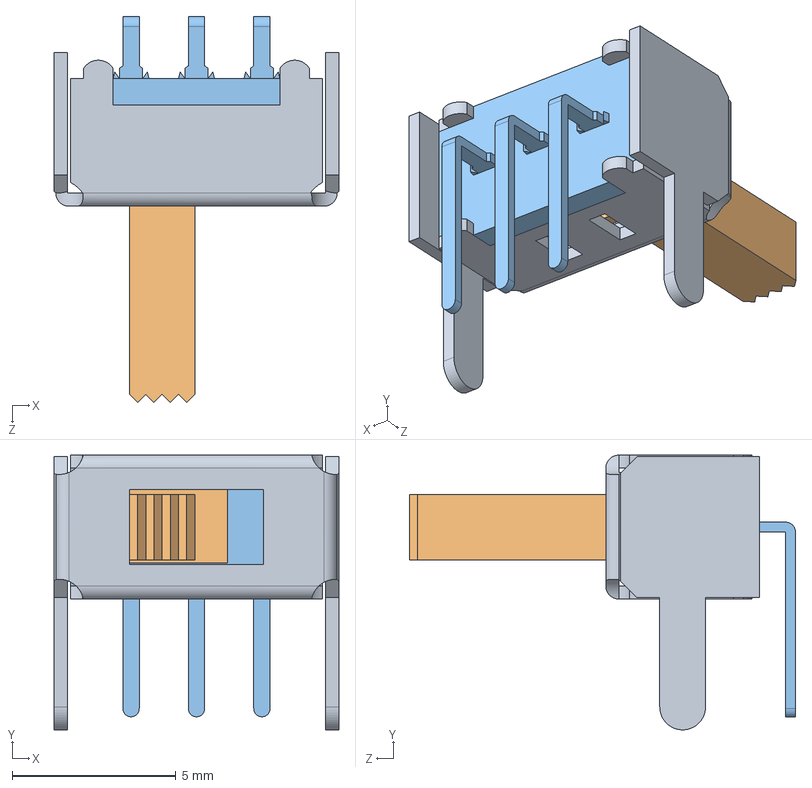
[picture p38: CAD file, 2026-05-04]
Hardware/RFID_ProjetKicad/LibrairiesExternes/RFID_3D/SLW-874744-6A-RA-N-D.step
8.70 x 8.40 x 11.8 mm

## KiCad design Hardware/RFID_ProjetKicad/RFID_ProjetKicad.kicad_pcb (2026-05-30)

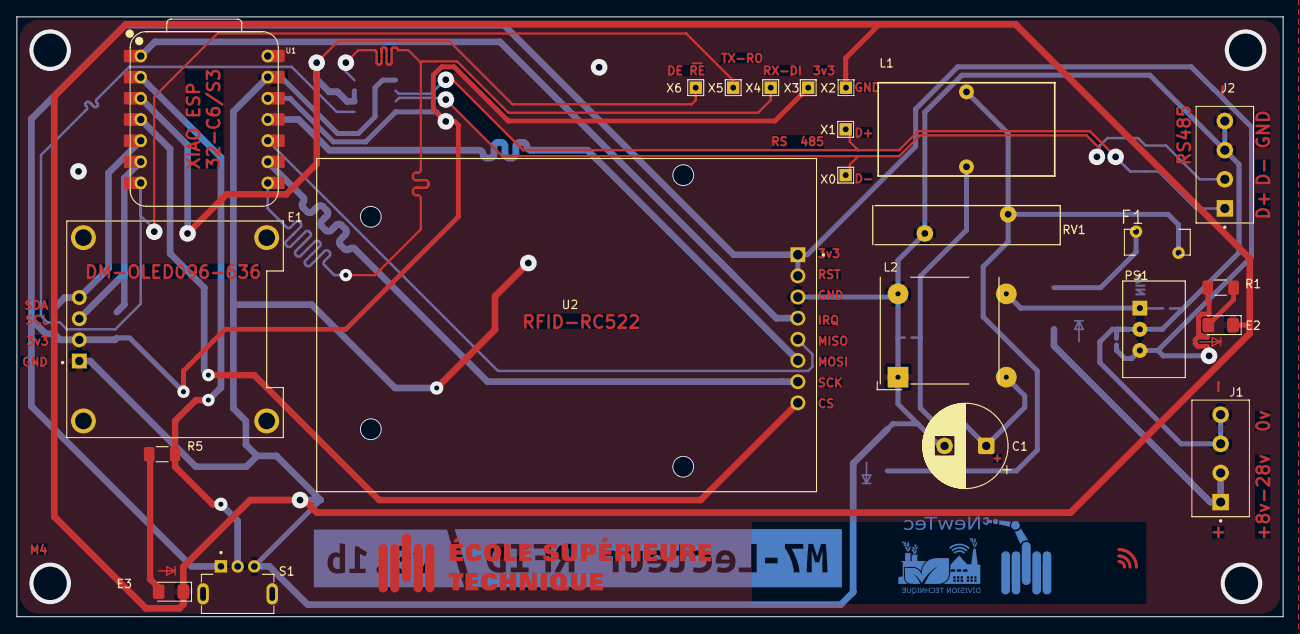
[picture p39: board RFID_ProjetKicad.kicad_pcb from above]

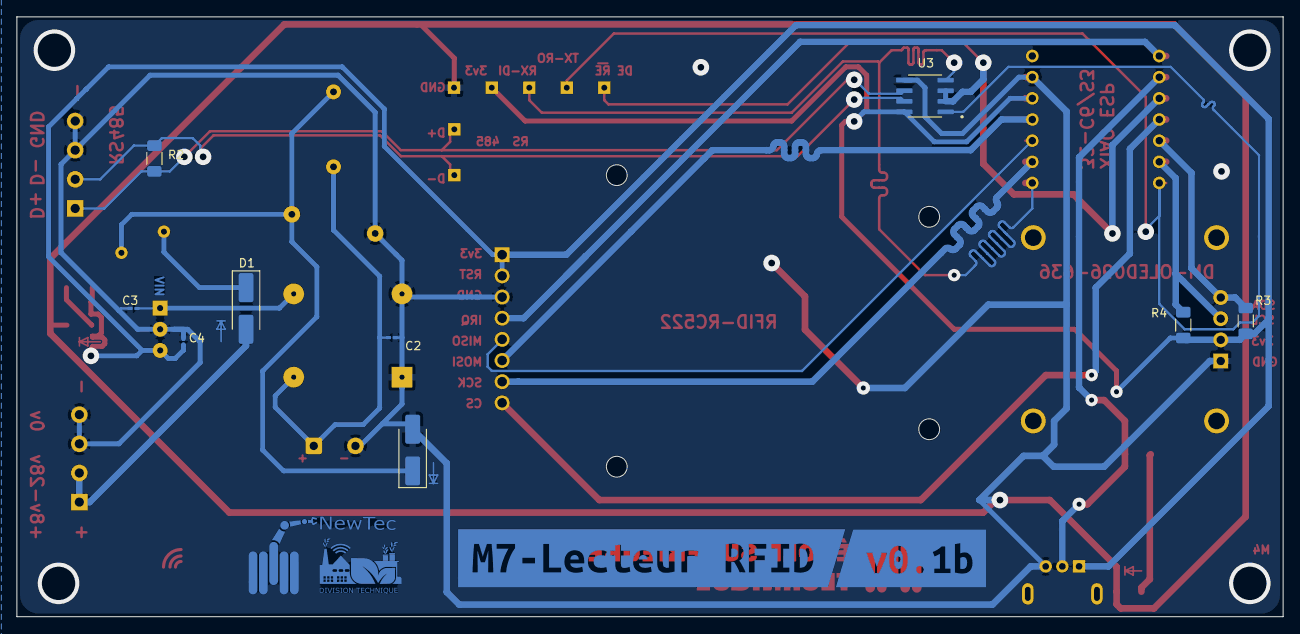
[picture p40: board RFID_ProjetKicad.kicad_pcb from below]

Board: 2 copper layers, 152.0 x 72.0 mm, 34 parts (11 on the bottom side), 22 nets.

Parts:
C1: 470µF; CP_Radial_D10.0mm_P5.00mm
C2: 4.7μF; C_0201_0603Metric_Pad0.64x0.40mm_HandSolder
C3: 10µF; C_0201_0603Metric_Pad0.64x0.40mm_HandSolder
C4: 22µF; C_0201_0603Metric_Pad0.64x0.40mm_HandSolder
D1: BX36_R1; D_SMA_Handsoldering
D2: SMAJ28A; D_SMA_Handsoldering
E1: DM-OLED096-636; MODULE_DM-OLED096-636
E2, E3: LED; LED_1206_3216Metric_Pad1.42x1.75mm_HandSolder
F1: PTC 1A; PTC
J1, J2: TB0011-350-04GR; SAMESKY_TB0011-350-04GR
L1: 300 µH; WE-FI_7447060
L2: 5 mH; SS11VL-11050
PS1: TSR_1-2433E; CONV_TSR_1-2433E
R1, R5: 68 R; R_1206_3216Metric_Pad1.30x1.75mm_HandSolder
R2: 120 R; R_1206_3216Metric_Pad1.30x1.75mm_HandSolder
R3, R4: 4k7; R_1206_3216Metric_Pad1.30x1.75mm_HandSolder
RV1: 20D470K; RV_Disc_D12mm_W4.7mm_P7.5mm
S1: SLW-874744; SW_SLW-874744-6A-RA-N-D
U1: XIAO-ESP32-C6-DIP
U2: RFID-RC522; MODULE_CEG006900
U3: MAX3485CSA_T; SOIC127P600X175-8N
X0, X1, X2, X3, X4, X5, X6: TestPoint_THTPad_1.5x1.5mm_Drill0.7mm
kibuzzard-6A1B3F22: G***; kibuzzard-6A1B3F22
kibuzzard-69FBB4E7: G***; kibuzzard-69FBB4E7

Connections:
+3V3: C4.1, E1.2 (VCC_IN), PS1.3 (+VOUT), R1.1, R3.1, R4.1, S1.1, U1.12 (3V3), U2.1 (VCC), U2.2 (RST), U3.8 (VCC), X3.1
+7V à 27.6V: D2.1 (A1), F1.2, L1.1, RV1.1
+8V à 28V: D1.2 (A), J1.1, J1.2
/D+: J2.1, R2.2, U3.6 (A), X1.1
/D-: J2.2, R2.1, U3.7 (B), X0.1
/SW_COM: R5.2, S1.2, U1.2 (GPIO1_A1_D1)
GND: C1.2, C2.2, C3.2, C4.2, D2.2 (A2), E1.1 (GND), E2.1 (K), E3.1 (K), J1.3, J1.4, J2.3, J2.4, L2.1, L2.4, PS1.2 (GND), RV1.2, S1.3, U1.13 (GND), U2.3 (GND), U3.5 (GND), X2.1
unnamed: C1.1, C2.1, L1.2, L2.2
unnamed: D1.1 (K), F1.1
unnamed: E1.3 (SCL), R4.2, U1.6 (GPIO23_D5_SCL)
unnamed: E1.4 (SDA), R3.2, U1.5 (GPIO22_D4_SDA)
unnamed: E2.2 (A), R1.2
unnamed: E3.2 (A), R5.1
unnamed: C3.1, L2.3, PS1.1 (+VIN)
unnamed: U1.1 (GPIO0_A0_D0), U2.4 (IRQ)
unnamed: U1.3 (GPIO2_A2_D2), U3.2 (~RE), U3.3 (DE), X6.1
unnamed: U1.7 (GPIO16_D6_TX), U3.1 (RO), X5.1
unnamed: U1.8 (GPIO17_D7_RX), U3.4 (DI), X4.1
unnamed: U1.11 (GPIO18_D10_MOSI), U2.6 (MOSI)
unnamed: U1.9 (GPIO19_D8_SCK), U2.7 (SCK)
unnamed: U1.10 (GPIO20_D9_MISO), U2.5 (MISO/SCL/TX)
unnamed: U1.4 (GPIO21_D3), U2.8 (SS/SDA/RX)

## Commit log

2026-04-30 Ajout des différents documents
    [HoferL - JournalPlanif - M7.xlsx]
2026-04-30 Ajout des repertoires
2026-04-30 Ajout dossier
    [HoferL - JournalPlanif - M7.xlsx, Matériel.xlsx]
2026-04-30 ajout concept détaillé
    [HoferL - JournalPlanif - M7.xlsx, Matériel.xlsx]
2026-05-01 Ajout choix composants
    [HoferL - JournalPlanif - M7.xlsx]
2026-05-01 Ajout des différentes recherches
    Ajout composant + list mat, ajout datasheet, ajout images
    [HoferL - JournalPlanif - M7.xlsx, Matériel.xlsx]
2026-05-04 Ajout de documents
    Schematic KiCad + modification rapport
    [Matériel.xlsx, RFID_ProjetKicad.kicad_pcb, RFID_ProjetKicad.kicad_sch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]
2026-05-04 Correction GitHub
    Readme, gitIgnore, suppression fichiers inutiles
    [HoferL - JournalPlanif - M7.xlsx]
2026-05-04 Création de la librairie du projet
    Fusion des bibliotheques + suppression fichier inutiles
    [DM-OLED096-636.step, HoferL - JournalPlanif - M7.xlsx, MAX3485CSA_T.step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]
2026-05-04 Ajout du schéma prototype d'ensemble
    [HoferL - JournalPlanif - M7.xlsx, Matériel.xlsx, RFID_ProjetKicad.kicad_sch]
2026-05-05 Refactor de l'alimentation
    [HoferL - JournalPlanif - M7.xlsx, Matériel.xlsx, RFID_ProjetKicad.kicad_sch]
2026-05-05 modification liste matériel avec lien vers datasheet
    [Matériel.xlsx]
2026-05-05 Suppression de fichiers inutiles
    [HoferL - JournalPlanif - M7.xlsx, Matériel.xlsx]
2026-05-05 Ajout de footprint + STEP files
    [HoferL - JournalPlanif - M7.xlsx, LED_1206_Orange.stp, MOV-20D470KTR.STEP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]
2026-05-05 Correction schéma et footprint
    Test PCB 3D : OKEY!
    [RFID_ProjetKicad.kicad_pcb, RFID_ProjetKicad.kicad_sch]
2026-05-05 Mise a jour de la documentation technique
    [HoferL - JournalPlanif - M7.xlsx, Matériel.xlsx]
2026-05-06 Création du PCB
    placement, routage et controle
    [HoferL - JournalPlanif - M7.xlsx, RFID_ProjetKicad.kicad_pcb, RFID_ProjetKicad.kicad_sch]
2026-05-06 Correction PCB + Logos
    [RFID_ProjetKicad.kicad_pcb]
2026-05-06 Ajout de points de test sur PCB
    [Matériel.xlsx, RFID_ProjetKicad.kicad_pcb]
2026-05-06 Ajout de la documentation sur l'implémentation PCB + Modification PCB et logos
    [HoferL - JournalPlanif - M7.xlsx, Matériel.xlsx, RFID_ProjetKicad.kicad_pcb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]
2026-05-06 Ajout de la fiche signalétique du projet
2026-05-07 Correction de la violation de la RDC
    Modification PCB
    [HoferL - JournalPlanif - M7.xlsx, RFID_ProjetKicad.kicad_pcb, RFID_ProjetKicad.kicad_sch]
2026-05-07 Ajout des choix pour le software
    [260507-CMD-Mouser-RFID par LHO.xlsm, HoferL - JournalPlanif - M7.xlsx]
2026-05-17 Ajout commande mat
    [260507-CMD-Mouser-RFID par LHO.xlsm, HoferL - JournalPlanif - M7.xlsx, Matériel.xlsx]
2026-05-30 Agrandissement des taille des pads
    [RFID_ProjetKicad.kicad_pcb, RFID_ProjetKicad.kicad_sch]
